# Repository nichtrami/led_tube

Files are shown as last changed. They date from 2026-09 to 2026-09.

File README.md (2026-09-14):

# LED Tube

## Overview
This project controls **2-meter-long LED tubes** built from a **WS2812B LED strip with 120 LEDs**.
The firmware runs on an **ESP32 (Arduino Core)** and supports standalone operation, a custom
**wireless DMX protocol over ESP-NOW**, wired **DMX input**, and an (experimental) **Art-Net** path.

The codebase builds two different devices from the same sources, selected via the `DEVICE_MODE`
build flag in [`platformio.ini`](platformio.ini):

| Device | PlatformIO env | Board | Role |
| --- | --- | ----- | ---- |
| **Tube** | `led_tube` | Seeed XIAO ESP32-S3 | Drives one LED tube and receives commands |
| **Bridge** | `bridge` | ESP32 dev board | Generates/forwards commands to the tubes  |

## Hardware Components
Schematics and PCB designs live in `pcb/`, enclosure models in `body/`.

Datasheets for the components used are not redistributed in this repository. The part numbers are
given in the schematics and can be looked up on the manufacturers' sites.

### User Interface (both devices)
- **Three buttons**: Up, Down, Enter
- **A monochrome 0.91" OLED display** (SSD1306) connected via **I2C**, showing the current menu item

## Operating Modes

### Tube
1. **Standalone** – the tube shows a locally selected color and effect.
2. **Wireless DMX** – the tube listens on a configurable DMX address and renders the data it
   receives from a bridge over ESP-NOW.

### Bridge
1. **Master** – generates beat-synchronized choreography (driven by a configurable BPM) for a
   configurable number of tubes and broadcasts it over ESP-NOW.
2. **DMX** – reads a wired DMX universe (via `esp_dmx`) and forwards the relevant slice to the
   tubes over ESP-NOW.
3. **Art-Net** – receives Art-Net over Ethernet (W5500). *Experimental / partially implemented.*

### Channels
The **Channel** menu item (1–3) maps to distinct Wi-Fi channels for the ESP-NOW link, so multiple
independent light systems can run side by side without interference. The bridge and its tubes must
use the same channel.

## Wireless Protocol
Communication uses **ESP-NOW broadcast** (no pairing). The payload is a lightweight DMX frame:

```
[ size (1 byte) ][ start_address (1 byte) ][ data ... up to 240 bytes ]
```

Each tube occupies `TUBE_DATASET_SIZE` (4) channels: `effect, red, green, blue`.

## Pin Configuration
Pins are defined in [`src/Config.hpp`](src/Config.hpp).

### Tube (Seeed XIAO ESP32-S3)
- **LED data**: GPIO 4
- **OLED (I2C)**: SDA GPIO 3, SCL GPIO 2
- **Buttons**: Up GPIO 9, Down GPIO 7, Enter GPIO 8

### Bridge (ESP32 dev board)
- **LED data**: GPIO 14
- **OLED (I2C)**: SDA GPIO 26, SCL GPIO 25
- **Buttons**: Up GPIO 27, Down GPIO 32, Enter GPIO 33
- **DMX input**: RX GPIO 16, EN/TX GPIO 17
- **Ethernet (W5500, SPI)**: CS GPIO 5, SCK GPIO 18, MISO GPIO 19, MOSI GPIO 23, RST GPIO 4

## Building & Flashing
This is a [PlatformIO](https://platformio.org/) project.

```bash
# Tube firmware
pio run -e led_tube -t upload

# Bridge firmware
pio run -e bridge -t upload
```

Configuration values selected in the on-device menu are persisted to NVS flash and restored on boot.

### Dependencies
Managed automatically by PlatformIO (see [`platformio.ini`](platformio.ini)):
- FastLED
- Adafruit GFX Library
- Adafruit SSD1306
- esp_dmx
- Ethernet
- ArtNet

ESP-NOW / Wi-Fi and `Preferences` (NVS) are provided by the ESP32 Arduino Core.

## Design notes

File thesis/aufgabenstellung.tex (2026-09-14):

% Eigenständig kompilierbare Aufgabenstellung.
% Kompilieren mit XeLaTeX oder LuaLaTeX (wegen fontspec/polyglossia), z. B.:
%   latexmk -xelatex aufgabenstellung_standalone.tex
\documentclass[a4paper,11pt]{article}

\usepackage{polyglossia}
\setdefaultlanguage[spelling=new,babelshorthands=true]{german}
\usepackage{fontspec}
\usepackage{parskip}
\usepackage[left=2.5cm,right=2.5cm,top=2.5cm,bottom=2.5cm]{geometry}

\title{Aufgabenstellung}
\author{}
\date{}

\begin{document}

\begin{center}
  {\Large\bfseries Entwicklung eines funkbasierten Beleuchtungssystems\\
  auf Basis von LED-Röhren für die Veranstaltungstechnik}\\[0.5em]
  {\large Aufgabenstellung}
\end{center}

\bigskip

Der Aufbau professioneller Bühnenbeleuchtung ist durch die kabelgebundene
DMX-Signalverteilung mit einem erheblichen Planungs-, Verkabelungs- und
Zeitaufwand verbunden. Kommerzielle Funklösungen adressieren dieses Problem,
sind jedoch kostenintensiv und primär auf große Produktionen ausgerichtet.
Ziel dieser Arbeit ist die Entwicklung eines kostengünstigen, funkbasierten
Beleuchtungssystems auf Basis von LED-Leuchtröhren, das DMX-Steuersignale
drahtlos an mehrere Beleuchtungseinheiten überträgt und sich ohne Anpassungen
in bestehende DMX-Infrastrukturen integrieren lässt. Das System soll dabei
durchgängig als frei zugängliches Open-Source-Projekt konzipiert und
veröffentlicht werden, um einen niedrigschwelligen Nachbau zu ermöglichen.
Das System besteht aus einer zentralen \emph{Bridge}, welche Steuerdaten
entgegennimmt und verteilt, sowie den empfangenden LED-Leuchtröhren, die die
Daten unmittelbar in Lichtsignale umsetzen.

Im Rahmen der Arbeit sind folgende Teilaufgaben zu bearbeiten:

\begin{itemize}
  \item Analyse des Einsatzszenarios und Ableitung funktionaler sowie
        nicht-funktionaler Anforderungen (u.\,a. Echtzeitverhalten,
        Zuverlässigkeit, Reichweite, Benutzerfreundlichkeit).
  \item Entwurf einer Systemarchitektur aus Bridge und Leuchtröhren auf Basis
        des ESP32 mit Definition eines schlanken, drahtlosen
        Übertragungsprotokolls (ESP-NOW) für die DMX-Datenverteilung.
  \item Implementierung der Firmware für die Betriebsmodi Einzelbetrieb,
        autonomer Master-Modus sowie drahtloser DMX-Modus mit Empfang
        kabelgebundener DMX512-Signale und Weiterleitung an adressierbare Leuchtröhren.
  \item Umsetzung der Ansteuerung der WS2815-LED-Strips, einer menügeführten
        Bedienung über OLED-Display und Taster sowie einer persistenten
        Konfigurationsspeicherung.
  \item Entwurf der Hardware in Form eigener Platinenlayouts (PCB) sowie der
        3D-Gehäuse für Bridge und Leuchtröhren unter Berücksichtigung der
        elektrischen Belastbarkeit und Portabilität.
  \item Experimentelle Evaluierung des Systems in einer realitätsnahen
        Umgebung hinsichtlich Verbindungsstabilität, Übertragungsrate, Latenz
        und Jitter sowie Ableitung verbleibender Optimierungspotenziale.
\end{itemize}

Sämtliche Ergebnisse -- Software, Platinenlayouts und Gehäusemodelle -- werden
als Open-Source-Projekt veröffentlicht, um Nachvollziehbarkeit und
Weiterentwicklung durch Dritte zu ermöglichen.

\end{document}

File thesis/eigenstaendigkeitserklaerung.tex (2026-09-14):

\section*{Eigenständigkeitserklärung}
\label{sec:eigenstaendigkeitserklaerung}

Ich versichere, dass ich diese Bachelorarbeit selbständig angefertigt, alle Hilfen und Hilfsmittel angegeben und alle
wörtlich oder dem Sinne nach aus Veröffentlichungen oder anderen Quellen, insbesondere dem Internet entnommenen
Inhalte, kenntlich gemacht habe. KI-Werkzeuge wurden in dieser Arbeit lediglich zur Korrektur von Rechtschreibung und Grammatik eingesetzt. 
Die Arbeit wurde bisher in gleicher oder ähnlicher Form keiner anderen Prüfungsbehörde vorgelegt und auch nicht veröffentlicht.

\vspace{2cm}

\noindent
\begin{tabular}{@{}p{0.45\textwidth}p{0.45\textwidth}@{}}
\textbf{Ort, Datum:} Leipzig, \today & \textbf{Unterschrift:} \hrulefill \\
\end{tabular}

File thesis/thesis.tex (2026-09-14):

\documentclass[a4paper,10pt]{report}

\usepackage{graphicx}
\usepackage{subcaption}
\usepackage{booktabs}
\usepackage{polyglossia}
\setdefaultlanguage[spelling=new,babelshorthands=true]{german}
\usepackage{fontspec}
\usepackage{parskip}
\usepackage{amsmath}
\usepackage{amsfonts}
\usepackage[backend=biber,style=numeric,babel=other]{biblatex}
\addbibresource{literatur.bib}
\usepackage[hidelinks]{hyperref}
\usepackage[left=2cm,right=2cm,top=3.0cm,bottom=3.0cm]{geometry}
\usepackage[arrow, matrix, curve]{xy}
\usepackage{msc}
\usepackage{float}
\usepackage{xcolor}
\usepackage[edges]{forest}
\usepackage{tikz}
\usetikzlibrary{positioning, arrows.meta, fit, backgrounds, decorations.pathreplacing}
\tikzset{
    archbox/.style   = {draw, rounded corners=2pt, align=center, inner sep=5pt,
                        minimum height=1.05cm, font=\small},
    extern/.style    = {archbox, fill=black!5},
    device/.style    = {archbox, fill=black!12, thick},
    modul/.style     = {archbox, fill=black!3, minimum width=3.3cm},
    huelle/.style    = {draw, dashed, rounded corners=4pt, inner sep=9pt},
    link/.style      = {-{Latex[length=2.2mm]}, thick},
    funk/.style      = {link, dashed},
    beschr/.style    = {font=\footnotesize, align=center, inner sep=2pt}
}
\usepackage{listings}
\lstset{
    language=Python,
    basicstyle=\ttfamily\small,
    keywordstyle=\color{purple}\bfseries,
    commentstyle=\color{gray}\itshape,
    stringstyle=\color{teal},
    numberstyle=\tiny\color{gray!60},
    identifierstyle=\color{black},
    backgroundcolor=\color{gray!5},
    frame=single,
    frameround=tttt,
    framerule=0.5pt,
    framexleftmargin=5pt,
    breaklines=true,
    showstringspaces=false,
    numbers=left,
    numbersep=10pt,
    tabsize=4,
    captionpos=b,
    xleftmargin=10pt,
    xrightmargin=5pt,
    emphstyle=\color{blue!80!black},
    emph={def,class,import,from,as,return,if,elif,else,for,while,try,except,with}
}
%\usepackage{draftwatermark}
%\SetWatermarkText{Entwurf}
%\nofiles

\begin{document}

% Deckblatt
\input{title}

%Abstract
\newpage
\input{abstract}

% Inhaltsverzeichnis
\setcounter{page}{1}
\pagenumbering{arabic}
\tableofcontents

%Leere Seite
\newpage
\null
\newpage

% Kapitel einbinden
\include{chapters/1_einleitung}
\include{chapters/2_grundlagen}
\include{chapters/3_stand_der_technik}
\include{chapters/4_anforderungsanalyse}
\include{chapters/5_systemarchitektur}
\include{chapters/6_implementierung}
\include{chapters/7_evaluierung}
\include{chapters/8_diskussion}

% Anhang
\appendix
\include{chapters/anhang}

% Literaturverzeichnis
\printbibliography

% Eigenständigkeitserklärung
\include{eigenstaendigkeitserklaerung}

\end{document}

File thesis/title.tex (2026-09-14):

\begin{titlepage}
    \vbox{ }
    \vbox{ }
    \begin{center}
% Upper part of the page

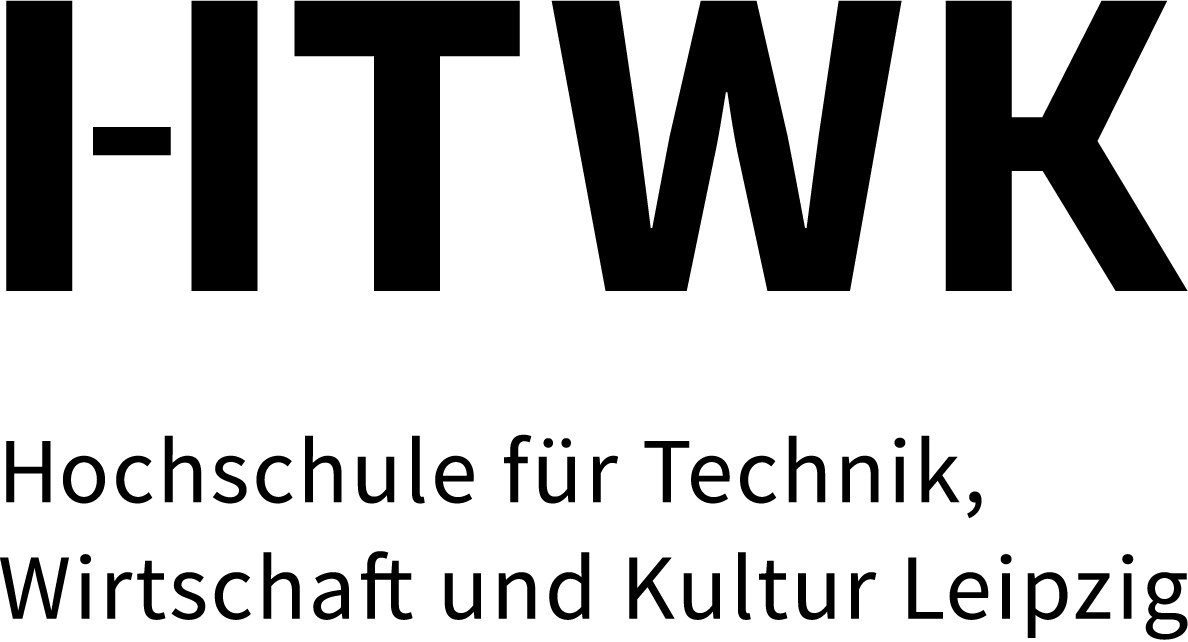
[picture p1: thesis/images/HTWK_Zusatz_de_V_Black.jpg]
        \\[1cm]
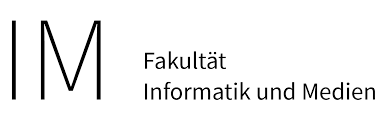
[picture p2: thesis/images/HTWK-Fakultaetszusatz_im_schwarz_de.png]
        \\[1cm]
        
        \vfill
        {\Large Abschlussarbeit zur Erlangung des akademischen Grades}\\[20pt]
        {\Large Bachelor of Science (B.Sc.)}\\[20pt]
        {\Large im Studiengang Bachelor Informatik}\\[10pt]
        {\Large der Fakultät Informatik und Medien}\\[20pt]
        \vbox{}

% Title
        {\LARGE \textbf{Entwicklung eines Beleuchtungssystems}}\\[10pt]
        {\LARGE \textbf{für Veranstaltungen als LED-Leuchtröhren}}\\[10pt]
        {\LARGE \textbf{mit funkgestützter Signalübertragung}}\\[40pt]
        {\Large Rami Hoßbach}\\[10pt]
        {\Large Leipzig, den \today}\\[20pt]
        \vfill

% Bottom of the page
        \begin{tabular}{l l}
            \Large Erstgutachter:  & \Large Prof. Dr.-Ing. Jens Wagner\\[10pt]
            \Large Zweitgutachter: & \Large M.Sc. Marian Ulbricht\\
        \end{tabular}
    \end{center}
\end{titlepage}

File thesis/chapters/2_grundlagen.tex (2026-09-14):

\chapter{Theoretische Grundlagen}
\label{chap:grundlagen}

\section{Eingebettete Systeme}
\label{sec:eingebettete-systeme}

Eingebettete Systeme werden von Marwedel als informationsverarbeitende Systeme 
definiert, die in in ein umgebendes Produkt eingebettet sind und dort dedizierte 
Steuerungs-, Regelungs- oder Überwachungsaufgaben übernehmen \cite{marwedel2021}. 
Im Gegensatz zu universellen Computersystemen sind sie auf einen konkreten 
Anwendungsfall zugeschnitten. Als gemeinsame Merkmale dieser Systemklasse nennt 
Marwedel insbesondere Echtzeitanforderungen sowie Anforderungen an Verlässlichkeit 
und Effizienz \cite{marwedel2021}, letztere äußert sich in ressourcensparender 
Hardware und häufig energiesparenden Betriebsweisen.

Die zunehmende Miniaturisierung und Leistungsfähigkeit moderner Mikrocontroller hat in 
den vergangenen Jahren zu einer breiten Durchdringung eingebetteter Systeme in 
unterschiedlichen Domänen geführt. Insbesondere die 
Integration drahtloser Kommunikationsschnittstellen wie WLAN und Bluetooth in 
kostengünstige Mikrocontroller-Plattformen eröffnet neue Möglichkeiten für verteilte, 
vernetzte Systemarchitekturen.

Im Kontext des entwickelten LED-Tube-Systems bilden eingebettete Systeme die zentrale 
Komponente sowohl der Bridge als auch der einzelnen Tubes. Beide setzen auf den 
ESP32-Mikrocontroller, der im Folgenden näher betrachtet wird.

\subsection{ESP32-Mikrocontroller}
\label{subsec:esp32}

Die Bezeichnung ESP32 steht nicht für einen einzelnen Chip, sondern für eine von 
Espressif Systems entwickelte Familie von System-on-Chips (SoC), deren Mitglieder sich 
in Prozessorarchitektur, Speicherausstattung und Peripherie unterscheiden 
\cite{espressif_esp32}. Kennzeichnend für die gesamte Familie ist die Integration eines 
leistungsfähigen Prozessors und umfangreicher drahtloser Kommunikationsschnittstellen 
(WLAN 802.11 b/g/n sowie Bluetooth beziehungsweise Bluetooth Low Energy) auf einem 
einzigen Baustein. Das namensgebende erste Mitglied der Familie kombiniert dabei einen 
Dual-Core-Prozessor des Typs Xtensa LX6 mit WLAN und Bluetooth 4.2. Seit der Einführung 
im Jahr 2016 hat sich die ESP32-Reihe zu einer der meistverwendeten Plattformen im 
Bereich des Internet of Things (IoT) und eingebetteter Systeme entwickelt. Besonders die 
Kompatibilität mit dem im Hobby- und Maker-Bereich weit verbreiteten Arduino-Ökosystem 
sowie die umfassende Unterstützung durch die Entwicklergemeinschaft haben zur 
Popularität des ESP32 beigetragen.

\subsubsection{Technische Merkmale}
\label{subsubsec:esp32-merkmale}

Es existieren verschiedene Varianten des ESP32, die sich in Bezug auf Speicherkapazität, Anzahl der GPIO-Pins,
integrierte Peripheriefunktionen und unterstützte Kommunikationsschnittstellen unterscheiden.
Die in diesem Projekt verwendeten Varianten verfügen über zwei unabhängige 32-Bit-Prozessorkerne mit einer maximalen 
Taktfrequenz von bis zu 240\,MHz. Diese Dual-Core-Architektur ermöglicht es, 
rechenintensive Aufgaben wie Signalverarbeitung und drahtlose Kommunikation parallel 
auszuführen.

Neben den Kommunikationsschnittstellen bieten die Bausteine der Familie umfangreiche 
Peripheriefunktionen, darunter mehrere UART-, SPI- und I²C-Schnittstellen, 
GPIO-Pins (General Purpose Input/Output), ADCs (Analog-Digital-Wandler), PWM-Kanäle 
(Pulse Width Modulation) sowie kapazitive Berührungssensoren \cite{espressif_esp32}. 

\subsubsection{Software-Entwicklung und Ökosystem}
\label{subsubsec:esp32-software}

Espressif Systems stellt mit dem ESP-IDF (Espressif IoT Development Framework) eine 
umfassende Entwicklungsumgebung bereit, die auf dem FreeRTOS-Echtzeitbetriebssystem 
basiert und native Unterstützung für C/C++-Programmierung bietet. Daneben existiert eine 
breite Community-Unterstützung für alternative Entwicklungsumgebungen wie Arduino IDE, 
PlatformIO sowie MicroPython.

Die Integration des ESP32 in Entwicklungsumgebungen sowie die Verfügbarkeit 
zahlreicher Open-Source-Bibliotheken haben die Einstiegshürde deutlich gesenkt und den 
Einsatz des Mikrocontrollers sowohl im Amateur- als auch im industriellen Kontext 
gefördert.

\subsubsection{Einsatz im entwickelten System}
\label{subsubsec:esp32-system}

Im Rahmen dieser Arbeit bildet der ESP32 die hardwaretechnische Grundlage sowohl für die 
zentrale Bridge als auch für die dezentralen LED-Tubes. Die Dual-Core-Architektur 
ermöglicht die parallele Verarbeitung von Netzwerkkommunikation (ESP-NOW, Art-Net) auf 
einem Kern und die Ansteuerung der LED-Hardware auf dem zweiten Kern.

Die integrierte WLAN-Funktionalität wird für die Implementierung des proprietären 
ESP-NOW-Protokolls genutzt, welches die drahtlose Datenübertragung zwischen Bridge und 
Tubes realisiert. Gleichzeitig erlaubt die Ethernet-Erweiterbarkeit über externe Module 
die Anbindung der Bridge an professionelle Lichtsteuersysteme mittels Art-Net.

Die GPIO-Pins dienen der Ansteuerung der Peripheriekomponenten, etwa der LED-Strips und 
der übrigen in der Schaltung verbauten ICs (Integrated Circuits).
Die Leistungsfähigkeit des ESP32 stellt sicher, dass die zeitkritischen Anforderungen der Lichtsteuerung erfüllt werden können, 
während gleichzeitig die Flexibilität für eventuelle zukünftige Erweiterungen gegeben ist.

\section{Kommunikationsprotokolle}
\label{sec:kommunikationsprotokolle}

\subsection{DMX512}
\label{subsec:dmx512}

DMX512 (Digital Multiplex 512) ist ein weit verbreiteter Industriestandard für die
Steuerung von Bühnen- und Veranstaltungstechnik. Der Standard wurde 1986 vom United 
States Institute for Theatre Technology (USITT) entwickelt und wird heute von der 
Entertainment Services and Technology Association (ESTA) gepflegt. Er wurde seither in 
mehreren Revisionen fortgeschrieben die aktuelle Fassung ist ANSI E1.11-2024 
\cite{ANSI_E1.11_2024}.

\subsubsection{Technische Grundlagen}
\label{subsubsec:dmx512-technik}

DMX512 überträgt Daten seriell und unidirektional über eine differentielle
RS-485-Leitung mit einer Datenrate von 250\,kbit/s \cite{ANSI_E1.11_2024}. Die
Übertragung erfolgt in Form von Paketen, die neben dem einleitenden START-Code bis zu
512 Datenfelder (Slots) umfassen. Jeder Slot wird durch einen 8-Bit-Wert (0--255)
repräsentiert, der beispielsweise die Helligkeit, Farbe oder Position eines Geräts
definiert.

Die physikalische Verbindung erfolgt über eine Daisy-Chain-Topologie, bei der die Geräte
in Reihe geschaltet werden. Der Standard schreibt vor, die Leitung abzuschließen, um
Reflexionen und die daraus folgenden Fehlfunktionen zu vermeiden als Abschluss ist ein
Widerstand von 120\,Ohm vorgesehen. Die Belastung einer DMX512-Linie ist zudem auf 32
Unit Loads begrenzt, wobei jeder Empfängereingang höchstens eine Unit Load darstellen
darf \cite{ANSI_E1.11_2024}. Größere Installationen erfordern daher Verstärker
(DMX-Splitter), die zugleich die nutzbare Leitungslänge erhöhen. Eine maximale
Leitungslänge legt der Standard selbst nicht fest, sie ergibt sich aus den elektrischen
Eigenschaften der RS-485-Strecke und liegt in der Praxis im Bereich einiger hundert
Meter.

\subsubsection{Protokollstruktur}
\label{subsubsec:dmx512-protokoll}

Ein DMX512-Paket beginnt mit einer Reset-Sequenz aus \textit{Break}, einer Unterbrechung
der Datenleitung, dem darauf folgenden \textit{Mark After Break} (MAB) und dem
\textit{START-Code}. Der START-Code kennzeichnet die Art der nachfolgenden Daten für
Beleuchtungsdaten ist der NULL-START-Code mit dem Wert 0x00 vorgesehen. Anschließend
folgen bis zu 512 Datenslots. Für die Zeiten der Reset-Sequenz unterscheidet der
Standard zwischen Sende- und Empfangsseite: Sender müssen einen Break von mindestens
92\,µs und einen MAB von mindestens 12\,µs erzeugen, während Empfänger bereits einen
Break ab 88\,µs und einen MAB ab 8\,µs als Paketbeginn erkennen müssen
\cite{ANSI_E1.11_2024}. Für die Implementierung des Empfängers ist somit die geringere,
für die des Senders die höhere Vorgabe maßgeblich.

Aus Datenrate und Paketaufbau ergibt sich für ein vollständiges Paket mit 513 Slots eine
minimale Aktualisierungszeit von 22,7\,ms und damit eine maximale Wiederholrate von
44\,Hz \cite{ANSI_E1.11_2024} werden weniger Slots übertragen, steigt die erreichbare
Rate entsprechend. Eine bidirektionale Kommunikation ist im regulären Datenpfad nicht
vorgesehen, sodass der Sender keine Rückmeldung über den Status der Empfangsgeräte
erhält.

\subsubsection{Einsatz in der Veranstaltungstechnik}
\label{subsubsec:dmx512-einsatz}

DMX512 hat sich als De-facto-Standard in der professionellen Lichtsteuerung etabliert
und wird von nahezu allen Herstellern unterstützt. Die Einfachheit des Protokolls sowie
die deterministischen Übertragungseigenschaften machen es besonders geeignet für
zeitkritische Anwendungen, bei denen eine zuverlässige Steuerung
erforderlich ist.

Im Kontext des entwickelten LED-Tube-Systems dient der Aufbau des DMX512-Pakets als
Vorbild für das interne Datenformat, in dem die Steuerbefehle repräsentiert werden. Die Bridge kann DMX-Daten sowohl über Art-Net 
(Ethernet) als auch über eine DMX-Schnittstelle (XLR) empfangen und verarbeitet 
diese anschließend zur Übertragung an die LED-Tubes. Dabei bildet die Struktur des 
DMX512-Frames die Grundlage für das entwickelte drahtlose Übertragungsprotokoll, das 
über ESP-NOW an die Tubes übertragen wird. 
Die Orientierung an diesem etablierten Standard ermöglicht eine nahtlose Integration in 
bestehende Lichtsteuersysteme und gewährleistet Kompatibilität mit professioneller 
Steuerungssoftware.

\subsection{Art-Net}
\label{subsec:artnet}

Art-Net ist ein Ethernet-basiertes Kommunikationsprotokoll, das von Artistic Licence
entwickelt wurde und die Übertragung von DMX512-Daten über IP-Netzwerke ermöglicht.
Seit seiner Einführung im Jahr 1998 hat sich Art-Net zu einem weit verbreiteten Standard
in der professionellen Lichtsteuerung entwickelt und wird von zahlreichen
Softwarelösungen und Hardwarekomponenten unterstützt.

Die Etablierung von Art-Net als De-facto-Standard in der professionellen 
Veranstaltungstechnik ist auf die Limitierung klassischer DMX512-Verbindungen 
zurückzuführen. Während eine einzelne DMX-Linie lediglich 512 Kanäle/Byte bereitstellt, 
erfordern moderne Installationen mit einer Vielzahl komplexer Scheinwerfer, 
LED-Pixelmatrizen oder hochauflösenden LED-Wänden häufig mehrere tausend Steuerkanäle. 
Die Art-Net-4-Spezifikation sieht ein theoretisches Maximum von 32.768 DMX-Universen 
vor, wie viele davon tatsächlich übertragen werden können, hängt von der verfügbaren 
Netzwerkbandbreite und der Leistungsfähigkeit der beteiligten Geräte ab 
\cite{artnet4}. Art-Net adressiert damit die gestiegenen Bandbreitenanforderungen 
professioneller Lichtinstallationen. Insbesondere bei der Ansteuerung von LED-Pixelmonitoren, 
bei denen jeder einzelne Pixel mehrere DMX-Kanäle (typischerweise RGB oder RGBW) 
beansprucht, stößt klassisches DMX512 schnell an seine Grenzen, während Art-Net eine 
skalierbare Lösung bietet.

\subsubsection{Funktionsweise und Architektur}
\label{subsubsec:artnet-funktion}

Art-Net kapselt DMX512-Daten in UDP-Pakete (User Datagram Protocol) und überträgt diese
über ein Standard-Ethernet-Netzwerk. Während eine DMX512-Linie auf ein einzelnes
RS-485-Segment mit einem Universum von 512 Kanälen beschränkt ist, ermöglicht Art-Net die
gleichzeitige Übertragung mehrerer Universen über eine einzige Netzwerkverbindung.

Ein Art-Net-Netzwerk besteht typischerweise aus einem oder mehreren \textit{Controllern}
(z.\,B. Lichtsteuerungssoftware), die Art-Net-Pakete senden, sowie \textit{Nodes}, die
diese Pakete empfangen und in DMX512-Signale umwandeln. Die Nodes können dabei sowohl
als Sender als auch als Empfänger fungieren, wodurch bidirektionale Kommunikation
möglich ist.

\subsubsection{Protokollstruktur}
\label{subsubsec:artnet-protokoll}

Jedes Art-Net-Paket beginnt mit einer acht Byte langen, nullterminierten Kennung, 
gefolgt von einem OpCode, der den Pakettyp bestimmt, der
Protokollversion sowie weiteren Verwaltungsinformationen \cite{artnet4}. Das Ziel wird
über die Port-Address adressiert, eine 15\,Bit breite Zahl, die sich aus den
Feldern Net, Sub-Net und Universe34 zusammensetzt und die 32.768 möglichen Universen
abbildet \cite{artnet4}. Der Nutzdatenbereich umfasst bis zu 512 Byte, entsprechend
einem DMX512-Universum.

\subsubsection{Vorteile gegenüber klassischem DMX512}
\label{subsubsec:artnet-vorteile}

Durch die Nutzung von Ethernet-Infrastruktur bietet Art-Net mehrere Vorteile gegenüber
klassischem DMX512:
\begin{itemize}
    \item \textbf{Skalierbarkeit:} Mehrere DMX-Universen können parallel über eine
          einzige Netzwerkverbindung übertragen werden.
    \item \textbf{Reichweite:} Die Ausdehnung ist nicht mehr durch die Grenzen eines
          einzelnen RS-485-Segments bestimmt, sondern kann mit
          Standard-Netzwerkkomponenten nahezu beliebig erweitert werden.
    \item \textbf{Bidirektionalität:} Rückmeldungen über Gerätestatus und Fehlerzustände sind möglich.
    \item \textbf{Flexibilität:} Bestehende IT-Infrastrukturen können genutzt werden,
          wodurch separate DMX-Verkabelung entfällt.
\end{itemize}

\subsubsection{Einsatz im entwickelten System}
\label{subsubsec:artnet-system}

Im entwickelten LED-Tube-System dient Art-Net als Schnittstelle zur Anbindung an
professionelle Lichtsteuerungssoftware. Die Bridge empfängt Art-Net-Pakete über ihre
Ethernet-Schnittstelle und extrahiert daraus die DMX512-Daten, die anschließend wie im
kabelgebundenen DMX-Betrieb weiterverarbeitet werden.

Darüber hinaus ist ein kabelgebundener Pixelsteuerungsmodus vorgesehen, in dem die
einzelnen Pixel der LED-Strips über eine Datenleitung angesprochen werden. Die Hardware
der Bridge ist dafür bereits vorbereitet
(Abschnitt~\ref{subsec:bridge-pcb}), die Umsetzung dieses Modus ist jedoch nicht
Gegenstand der vorliegenden Arbeit. Durch die Unterstützung von Art-Net bleibt das System
mit einer Vielzahl bestehender Steuerungslösungen kompatibel.

\section{Drahtlose Kommunikation}
\label{sec:drahtlose-kommunikation}

Drahtlose Kommunikation stellt einen zentralen Bestandteil moderner eingebetteter
Systeme dar, insbesondere im Kontext verteilter Architekturen und modularer
Installationen. Im Vergleich zu kabelgebundenen Kommunikationsformen bietet sie eine
höhere Flexibilität und vereinfacht die physische Integration einzelner Komponenten.
Gleichzeitig ergeben sich jedoch neue Herausforderungen hinsichtlich Latenz,
Zuverlässigkeit, Störanfälligkeit und Energieeffizienz.

Im vorliegenden System wird drahtlose Kommunikation eingesetzt, um Steuerdaten von einer
zentralen Bridge an mehrere räumlich verteilte LED-Tubes zu übertragen. Zunächst werden
das genutzte Frequenzband und der Zugriff auf das Übertragungsmedium betrachtet, da
beide das Verhalten der Funkstrecke unter Last bestimmen. anschließend wird das
eingesetzte Protokoll ESP-NOW vorgestellt.

\subsection{Das 2,4-GHz-Band und der Zugriff auf das Übertragungsmedium}
\label{subsec:24ghz-medienzugriff}

Die Übertragung erfolgt im Frequenzbereich von 2400 bis 2483,5\,MHz. Dieses Band steht
weltweit anmeldefrei zur Verfügung. in Europa regelt die harmonisierte Norm
ETSI EN 300 328 die Nutzung durch Breitband-Datenübertragungssysteme
\cite{etsi_en300328}. Genutzt wird es nicht exklusiv, sondern gemeinsam von WLAN,
Bluetooth, Zigbee und weiteren Funkanwendungen, die die genannte Norm ausdrücklich
gemeinsam erfasst. Für ein Steuerungssystem
folgt daraus, dass die verfügbare Übertragungskapazität nicht allein von der eigenen
Hardware abhängt, sondern von der Belegung des Kanals durch fremde Sender.

Innerhalb des Bands definiert IEEE 802.11 in Europa dreizehn Kanäle im Abstand von je
5\,MHz, während ein Kanal eine Bandbreite von etwa 20\,MHz belegt. 

Der Zugriff auf das gemeinsam genutzte Medium erfolgt nach dem in IEEE 802.11
festgelegten Verfahren CSMA/CA (Carrier Sense Multiple Access with Collision
Avoidance) \cite{ieee80211_2024}. Eine Station prüft vor dem Senden, ob der Kanal frei
ist, wartet bei belegtem Kanal ab und beginnt die Übertragung erst nach einer zusätzlich
zufällig gewählten Wartezeit (Backoff). Kollisionen werden dadurch vermieden, gleichzeitig verzögern sich
Sendevorgänge bei hoher Fremdlast oder unterbleiben ganz. Für die Bewertung der
Zuverlässigkeit ist diese Unterscheidung wesentlich: Eine ausgelastete Umgebung führt
nicht zu verfälschten, sondern zu verspäteten oder ausbleibenden Paketen. Die
messtechnische Untersuchung dieses Effekts erfolgt in
Abschnitt~\ref{sec:stoerfestigkeit}.

\subsection{ESP-NOW}
\label{subsec:espnow-protokoll}
Das von Espressif Systems entwickelte ESP-NOW-Protokoll stellt eine proprietäre, verbindungslose 
Kommunikationstechnologie dar, die primär für Low-Power-Anwendungen im Bereich des Internet of Things (IoT) konzipiert wurde. 
Im Gegensatz zu herkömmlichen WLAN-Verbindungen nach dem IEEE 802.11-Standard, welche eine zeit- und 
energieintensive Assoziierung mit einem Access Point sowie den vollständigen Durchlauf des TCP/IP-Stacks erfordern, 
operiert ESP-NOW unmittelbar auf der Sicherungsschicht (Data Link Layer) des ISO-OSI-Modells.

Technisch basiert die Übertragung auf sogenannten \textit{IEEE 802.11 Vendor Specific Action Frames} \cite{espressif_espnow}. 
Diese ermöglichen es den Knotenpunkten, Datenpakete direkt über die MAC-Adresse zu adressieren, ohne dass ein 
vorheriger Handshake oder eine IP-Zuweisung notwendig ist. Daraus resultiert eine signifikante Reduktion 
der Latenzzeit sowie des energetischen Overheads, da die Funkmodule lediglich für die Dauer der Übertragung aktiviert werden müssen.

Trotz der verbindungslosen Natur unterstützt das Protokoll eine optionale bidirektionale 
Kommunikation durch Bestätigungs-Frames (Acknowledgements) sowie eine Verschlüsselung der 
Action Frames \cite{espressif_espnow}. Die maximale Nutzlast 
je Datenpaket beträgt in der ersten Version 250 Byte und wurde in der zweiten 
Version auf 1470 Byte erhöht \cite{espressif_espnow}. Mit Version 1.0 lässt sich somit nur 
etwa ein halber DMX512-Frame übertragen, während Version 2.0 ein vollständiges 
DMX-Universum in einem einzigen Paket aufnehmen kann.

Version 2 ist abwärtskompatibel zu Version 1, sodass ältere Geräte weiterhin mit der neuen Version kommunizieren können, 
jedoch nur die geringere Payload-Größe von 250 Byte nutzen können.
Die Standard-Übertragungsrate gibt Espressif mit 1\,Mbit/s an \cite{espressif_espnow}.

ESP-NOW verwendet ein Peer-to-Peer- beziehungsweise Broadcast-Kommunikationsmodell, bei
dem Datenpakete direkt zwischen den beteiligten Knoten ausgetauscht werden. Für die
gerichtete Übertragung muss jeder Empfänger zuvor als Peer registriert werden, wobei die
Zahl gleichzeitig registrierter Peers auf 20 begrenzt ist \cite{espressif_espnow}. Diese
Begrenzung entfällt im Broadcast-Betrieb, da dort sämtliche Empfänger über eine einzige
Broadcast-Adresse erreicht werden.

\subsubsection{Latenz, Zuverlässigkeit und Einschränkungen}
\label{subsubsec:espnow-eigenschaften}

Durch den Verzicht auf den vollständigen WLAN-Stack weist ESP-NOW in der Regel eine
geringere Latenz als klassische WLAN-Kommunikation auf. Gleichzeitig existieren jedoch
keine integrierten Mechanismen zur garantierten Zustellung oder zur Reihenfolgekontrolle
von Paketen. Der Sendestatus, den die Anwendung nach einem Sendevorgang erhält, bezieht
sich ausschließlich auf die MAC-Schicht, ob die Daten die Anwendungsschicht des
Empfängers erreichen, ist damit ausdrücklich nicht sichergestellt
\cite{espressif_espnow}.

Die Zuverlässigkeit der Übertragung hängt daher stark von den Umgebungsbedingungen, der
Anzahl der beteiligten Knoten sowie der Paketfrequenz ab. Da ESP-NOW auf 802.11-Frames
aufsetzt, unterliegt es zudem dem in
Abschnitt~\ref{subsec:24ghz-medienzugriff} beschriebenen Medienzugriff: Bei hoher
Kanalauslastung verzögern sich Sendevorgänge oder unterbleiben ganz. Paketverluste sind
somit prinzipiell möglich und müssen auf Anwendungsebene berücksichtigt werden.

\subsubsection{Bedeutung für das entwickelte System}
\label{subsubsec:espnow-system}

ESP-NOW bildet die Grundlage für die drahtlose Übertragung von DMX-Steuerdaten von der
Bridge zu den LED-Tubes. Die geringe Latenz und der geringe Overhead machen das
Protokoll besonders geeignet für zeitkritische Steuerinformationen, wie sie in der
Lichtsteuerung erforderlich sind.

Gleichzeitig stellt die fehlende Zustellgarantie eine zentrale Herausforderung dar, die
im Rahmen dieser Arbeit durch experimentelle Untersuchungen der Verbindungsstabilität
analysiert wird. Die Ergebnisse dieser Untersuchungen bilden die Basis für die Bewertung
der Eignung von ESP-NOW als drahtlose Alternative zu kabelgebundenen DMX-Verbindungen.

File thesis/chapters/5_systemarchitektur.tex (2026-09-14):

\chapter{Systemarchitektur}
\label{chap:systemarchitektur}

Basierend auf den im vorherigen Kapitel ermittelten Anforderungen wird im Folgenden die 
Systemarchitektur des drahtlosen Beleuchtungssystems vorgestellt. 
Die Architektur beschreibt die grundlegende Struktur des Systems, die ausgewählten 
Hardwarekomponenten sowie deren Zusammenwirken zur Realisierung der angestrebten Funktionalität. 
Während dieses Kapitel die konzeptionellen und strukturellen Entscheidungen – insbesondere 
hinsichtlich der Hardware – aufzeigt, wird die konkrete technische Umsetzung 
in Kapitel~\ref{chap:implementierung} (Implementierung) behandelt.

\section{Systemüberblick}
\label{sec:systemueberblick}

Das entworfene System setzt sich aus zwei Hauptkomponenten zusammen: einer zentralen Sendeeinheit (Bridge) und 
mehreren dezentralen Empfangseinheiten (LED-Leuchtröhren). 
Die Bridge fungiert als zentraler Kommunikationsknotenpunkt, welcher externe Steuersignale 
aus der Veranstaltungstechnik – wahlweise über DMX oder Art-Net – entgegennimmt, verarbeitet und in 
ein systeminternes Protokoll übersetzt. 
Anschließend verteilt sie die Daten drahtlos an die angeschlossenen Leuchtröhren.

Die LED-Leuchtröhren agieren als verteilte Aktoren. 
Sie empfangen die von der Bridge ausgesendeten Steuerdaten und setzen diese unmittelbar in Lichtsignale um. 
Darüber hinaus verfügen sie über einen autarken Standalone-Modus, bei dem keine Verbindung zur Bridge notwendig ist. 

Aus dieser Aufteilung ergeben sich die im Folgenden beschriebenen Strukturen: der
Signalfluss je Betriebsmodus, die Auswahl der Hardwarekomponenten, die Gliederung der
Software sowie die Verfahren, mit denen die Daten zwischen den Komponenten übertragen
und verarbeitet werden.

Abbildung~\ref{fig:systemueberblick} zeigt die Komponenten des Systems und die
Verbindungen zwischen ihnen.

\begin{figure}[H]
    \centering
    \begin{tikzpicture}[node distance=1.1cm and 2.3cm]
        \node[extern] (pult) {Lichtsteuerung\\(Pult oder Software)};
        \node[device, right=of pult] (bridge) {\textbf{Bridge}\\ESP32};
        \node[archbox, right=of bridge, yshift=1.7cm] (t1)
            {Leuchtröhre 1\\\footnotesize XIAO ESP32-S3 + WS2815};
        \node[archbox, right=of bridge] (t2)
            {Leuchtröhre 2\\\footnotesize XIAO ESP32-S3 + WS2815};
        \node[archbox, right=of bridge, yshift=-1.7cm] (tn)
            {Leuchtröhre $n$\\\footnotesize XIAO ESP32-S3 + WS2815};

        \draw[link] (pult) -- node[beschr, above] {DMX512\\Art-Net} (bridge);
        \draw[funk] (bridge) -- (t1);
        \draw[funk] (bridge) -- node[beschr, above] {ESP-NOW} (t2);
        \draw[funk] (bridge) -- (tn);

        \node[beschr, below=0.15cm of bridge] {lokales Bedienmenü};
        \node[beschr, below=0.15cm of tn] {lokales Bedienmenü};
    \end{tikzpicture}
    \caption{Systemüberblick: Die Bridge verteilt das kabelgebunden empfangene Steuersignal per Broadcast an alle Leuchtröhren.}
    \label{fig:systemueberblick}
\end{figure}

\section{Betriebsmodi und Signalfluss}
\label{sec:betriebsmodi-signalfluss}

Der Signalfluss im System variiert je nach Betriebsmodus, wobei die grundlegenden Datenpfade und 
Interaktionen zwischen den Komponenten im Folgenden erläutert werden.

 \subsection{Standalone-Modus (Leuchtröhre)}
\label{subsec:signalfluss-einzelbetrieb}

Im Standalone-Modus agieren die LED-Leuchtröhren autark, ohne eine Verbindung zur Bridge.
Die Steuerung erfolgt über die integrierte Benutzeroberfläche der Röhren, bestehend aus 
einem OLED-Display und Navigationsschaltern.
Der interne Controller der Röhre generiert die Lichtsignale basierend auf den Benutzereingaben 
und schickt diese direkt an die LEDs weiter.
In diesem Modus findet keine Kommunikation mit der Bridge statt, und die Röhren arbeiten unabhängig voneinander.

\subsection{DMX-Modus}
\label{subsec:signalfluss-dmx-betrieb}

Im DMX-Modus empfängt die Bridge die Steuerdaten über die DMX- oder die Art-Net-Schnittstelle, verarbeitet diese und leitet 
sie drahtlos an die Leuchtröhren weiter.
Die Bridge fungiert als DMX-zu-ESP-NOW-Gateway: Die DMX-Daten werden in ein internes, an
DMX angelehntes Protokoll übersetzt und über das integrierte Wi-Fi-Modul an die Röhren
gesendet.
Der Controller der Röhre empfängt die Daten über das integrierte Wi-Fi-Modul, validiert diese und setzt sie 
in die entsprechenden LED-Signale um.
Die Steuerbefehle pro Röhre enthalten 4 Bytes. 1 Byte für die Wahl eines vordefinierten Effekts und 3 Bytes für die RGB-Farbwerte.

Welche der beiden Eingangsschnittstellen die Bridge auswertet, wird an ihrem Bedienmenü als
eigener Eintrag der Moduswahl festgelegt: Der DMX-Modus liest das Universum über die
RS-485-Schnittstelle ein, der Art-Net-Modus über die Ethernet-Schnittstelle. Diese
Unterscheidung betrifft ausschließlich die Empfangsstufe der Bridge. Ab der Überführung in
das interne Transportformat sind beide Pfade identisch. Für die Leuchtröhren ist die
Herkunft des Universums nicht erkennbar, sie verbleiben in beiden Fällen im DMX-Modus.
\begin{figure}[H]
	\centering
	
	\caption{Signalfluss im DMX-Modus}
	\label{fig:signalfluss-dmx-betrieb}
\end{figure}

\section{Hardware-Architektur}
\label{sec:hardware-architektur}

Die Auswahl der Hardwarekomponenten erfolgte primär unter den Gesichtspunkten der Rechenleistung für 
Echtzeitverarbeitung, der Verfügbarkeit notwendiger Kommunikationsschnittstellen sowie der räumlichen und 
energetischen Restriktionen. Als Basis für beide Systemkomponenten wurden Mikrocontroller der ESP32-Familie gewählt. 
Diese bieten neben einer hohen Taktrate und ausreichend GPIO-Pins vor allem eine integrierte Wi-Fi-Schnittstelle, welche 
die geforderte drahtlose Vernetzung ohne zusätzliche externe Funkmodule ermöglichen und somit das Systemdesign verschlanken.
Abbildung~\ref{fig:hardware-architektur} stellt den Aufbau beider Geräte gegenüber.

\begin{figure}[H]
    \centering
    \begin{tikzpicture}[x=1cm, y=1cm]
        % --- Bridge ---
        \node[archbox, minimum width=3.2cm] (in)   at (0,0)      {DMX512 (RS-485)\\Art-Net (Ethernet)};
        \node[device,  minimum width=2.8cm] (esp)  at (4.9,0)    {ESP32-32U};
        \node[archbox, minimum width=2.4cm] (ant1) at (9.2,0)    {externe Antenne};
        \node[archbox, minimum width=2.8cm] (ui1)  at (4.9,-1.9) {OLED-Display\\+ 3 Taster};

        \draw[link] (in)  -- (esp);
        \draw[link] (esp) -- (ant1);
        \draw[link, {Latex[length=2mm]}-{Latex[length=2mm]}] (esp) -- (ui1);
        \node[beschr, right=0.25cm of ui1] {Versorgung: 5\,V über USB-C};

        \begin{scope}[on background layer]
            \node[huelle, fit=(in)(esp)(ant1)(ui1),
                  label={[font=\small\bfseries]above:Bridge}] {};
        \end{scope}

        % --- Leuchtröhre ---
        \node[archbox, minimum width=3.2cm] (strip) at (0,-5.2)   {WS2815-Strip\\\footnotesize 120 Pixel};
        \node[device,  minimum width=2.8cm] (xiao)  at (4.9,-5.2) {XIAO ESP32-S3};
        \node[archbox, minimum width=2.4cm] (ant2)  at (9.2,-5.2) {externe Antenne};
        \node[extern,  minimum width=3.2cm] (pwr2)  at (0,-7.3)   {12\,V-Netzteil};
        \node[archbox, minimum width=2.8cm] (buck)  at (4.9,-7.3) {Step-Down\\\footnotesize 12\,V $\rightarrow$ 5\,V};
        \node[archbox, minimum width=2.4cm] (ui2)   at (9.2,-7.3) {OLED-Display\\+ 3 Taster};

        \draw[link] (xiao) -- (strip);
        \draw[link] (ant2) -- (xiao);
        \draw[link] (pwr2) -- (strip);
        \draw[link] (pwr2) -- (buck);
        \draw[link] (buck) -- (xiao);
        \draw[link, {Latex[length=2mm]}-{Latex[length=2mm]}] (ui2) -- (xiao);

        \begin{scope}[on background layer]
            \node[huelle, fit=(strip)(xiao)(ant2)(pwr2)(buck)(ui2),
                  label={[font=\small\bfseries]above:Leuchtröhre}] {};
        \end{scope}

        \draw[funk] (ant1) -- node[beschr, right=1mm, pos=0.62] {ESP-NOW} (ant2);
    \end{tikzpicture}
    \caption{Hardware-Architektur beider Gerätetypen: gemeinsame Bedienhardware und gemeinsamer Funkweg, unterschiedliche Schnittstellen.}
    \label{fig:hardware-architektur}
\end{figure}

\subsection{Bridge}
\label{subsec:bridge-hardware}

Die Bridge übernimmt die Aufgabe der Protokollkonvertierung und Datenverteilung. 
Als zentrale Steuereinheit kommt ein ESP32-32U Entwicklungsboard zum Einsatz. Dieser Mikrocontroller bietet 
die entsprechende Rechenleistung um die Echtzeitverarbeitung der eingehenden DMX- und Art-Net-Datenströme zu gewährleisten, 
und verfügt über ausreichend GPIOs für die Anbindung der notwendigen Peripherie.

Zur physikalischen Integration in die bestehende Infrastruktur ist die Bridge mit dedizierten Schnittstellen ausgestattet. 
Für den DMX-Empfang wird ein RS-485-Transceiver (SN75176) verwendet, der als Pegelwandler zwischen den 
differenziellen DMX-Signalen nach RS-485-Standard und den TTL-Signalen des ESP32 agiert. 
Für den Art-Net-Betriebsmodus ist ein Ethernet-Modul vom Typ USR-ES1 integriert, welches den physikalischen 
Netzwerkzugriff für den Art-Net-Empfang gewährleistet.

Die Weiterleitung der verarbeiteten Steuerdaten an die Leuchtröhren erfolgt über das integrierte 
Wi-Fi-Modul des ESP32. Zur Erhöhung der Reichweite und Kommunikationsstabilität im störanfälligen Bühnenumfeld ist 
eine externe Antenne vorgesehen.

Die primäre Spannungsversorgung der Bridge-Komponenten erfolgt per 5V-USB-C-Anschluss direkt über das ESP32-Development-Board. 
Zur Erfüllung der Anforderungen bezüglich Systemkonfiguration und Benutzerfreundlichkeit verfügt das Bedienpanel über 
ein monochromes OLED-Display sowie drei Taster für die Menüführung. 
Es wurde exakt dieselbe Hardwarekombination wie bei der Röhre gewählt, um die Handhabung 
intuitiv und komponentenübergreifend einheitlich zu gestalten.

\subsection{LED-Leuchtröhren}
\label{subsec:led-leuchtroehren-hardware}

Die LED-Leuchtröhren unterliegen baulichen Beschränkungen aufgrund des schlanken Formfaktors bei einem Außendurchmesser von 40\,mm. 
Aus diesem Grund wurde für die Steuerung der \textit{XIAO ESP32-S3} Mikrocontroller ausgewählt. 
Dieser zeichnet sich durch einen besonders kleinen Formfaktor bei ausreichend verfügbaren GPIO-Pins 
und einem dedizierten Anschluss für eine externe WLAN-Antenne aus.

Als Leuchtmittel werden LED-Streifen des Typs WS2815 mit einer Dichte von 60 LEDs pro Meter verwendet. 
Der WS2815 teilt dasselbe Kommunikationsprotokoll wie der weitverbreitete WS2812B (5V-TTL-Logikpegel), 
verfügt jedoch über einen integrierten Spannungsregler und wird mit einer Arbeitsspannung von 12V betrieben. 
Die Anhebung der Betriebsspannung verringert den Spannungsabfall bei längeren Kabel- und
Streckenführungen. Zudem müssen die verwendeten Komponenten nur auf geringere
Stromstärken ausgelegt werden.

Der zusätzliche schaltungstechnische Aufwand zur Erzeugung der Betriebsspannung von 5V (für die restliche Elektronik) wird 
durch die Vorteile der 12V-LED-Architektur kompensiert. 
Zur Realisierung kommt ein kompakter DC-DC-Step-Down-Wandler zum Einsatz, der die von einem externen 12V-Netzteil 
bezogene Eingangsspannung auf 5V reduziert. 
Da der XIAO ESP32-S3 über einen eigenen On-Board-Spannungsregler verfügt, kann das 5V-Niveau direkt 
an dessen VCC-Eingangspin anliegen. 
Dieser transformiert die anliegende Spannung weiter auf die nominelle Chipspannung von 3,3V.

Für die Kommunikation kommen bei den Röhren die reziproken Gegenstücke der Bridge-Sender zum Einsatz: 
Das drahtlose Signal wird über die Wi-Fi-Schnittstelle des ESP32-S3 (mit externer Antenne) demoduliert.

Wie beim Steuergerät umfasst das Human-Machine-Interface auch hier ein monochromes OLED-Display 
sowie drei Navigationsschalter. 
Die konkreten Pinzuteilungen, Schaltungsdetails und Platinenentwürfe der Baugruppen
werden in Kapitel~\ref{chap:implementierung} erläutert.

\section{Software-Architektur}
\label{sec:software-architektur}

Das Software-Design des Systems folgt einem modularen und objektorientierten Ansatz. 
Ein zentraler Aspekt der Architektur ist die Verwendung derselben Codebasis für beide 
Geräteklassen (Bridge und Leuchtröhre). Durch bedingte Kompilierung wird mittels Umgebungsvariablen je nach 
Zielsystem entschieden, welche Logikblöcke eingebunden werden, was Redundanzen vermeidet und 
die Wartbarkeit erhöht.
Abbildung~\ref{fig:software-architektur} zeigt die resultierende Gliederung.

\begin{figure}[H]
    \centering
    \begin{tikzpicture}[x=1cm, y=1cm]
        \node[device, text width=4.7cm, align=center] (bfw) at (0,0)
            {\textbf{Bridge-Firmware}\\[2pt]\footnotesize DMX- und Art-Net-Eingang,
             Effektgenerierung im Master-Modus, Adressvergabe};
        \node[device, text width=4.7cm, align=center] (tfw) at (6.4,0)
            {\textbf{Leuchtröhren-Firmware}\\[2pt]\footnotesize Funkempfang, Auswertung
             der eigenen Adresse, Rendering};

        \node[modul] (m1) at (-1.3,-2.9) {Menü und Display};
        \node[modul] (m2) at (3.2,-2.9)  {Drahtlose Kommunikation};
        \node[modul] (m3) at (7.7,-2.9)  {LED-Steuerung};

        \begin{scope}[on background layer]
            \node[huelle, fit=(m1)(m2)(m3),
                  label={[font=\small\bfseries]below:Gemeinsame Module}] (hull) {};
        \end{scope}

        \draw[link] (bfw.south) -- (hull.north -| bfw.south);
        \draw[link] (tfw.south) -- (hull.north -| tfw.south);
    \end{tikzpicture}
    \caption{Gliederung der Software: gemeinsame Hardwareabstraktion, zur Übersetzungszeit ausgewählte gerätespezifische Firmware.}
    \label{fig:software-architektur}
\end{figure}

\subsection{Modulare Struktur und geteilte Komponenten}
\label{subsec:gemeinsame-softwarekomponenten}

Um die Kernfunktionen abzubilden, ist die Software in funktional getrennte Module unterteilt, 
die geräteübergreifend grundlegende Aufgaben zur Hardwareabstraktion übernehmen:

\begin{itemize}
    \item \textbf{Benutzerinteraktion (Menü und Display):} Kapselt die Verwaltung lokaler 
    Einstellungen, sichert Konfigurationen persistent und visualisiert Systemparameter für den Nutzer.
    \item \textbf{Drahtlose Kommunikation:} Stellt eine generische Abstraktionsschicht 
    für das Senden und Empfangen der systeminternen Datenpakete über das Funknetzwerk bereit.
    \item \textbf{Lichterzeugung (LED-Controller):} Übernimmt die logische Übersetzung von 
    rohen Datenwerten (Farben, Parameter oder Pixelarrays) in dynamische Lichtsignale
\end{itemize}

Ein übergeordneter Steuerungsprozess orchestriert diese Module, aktualisiert das System und 
etabliert – abhängig vom aktuellen Betriebsmodus – den direkten Datenfluss zwischen Peripherie 
und Aktoren.

\subsection{Gerätespezifische Firmware-Profile}
\label{subsec:geraetespezifische-firmware}

Aufbauend auf den gemeinsamen Modulen fokussieren sich Bridge und Leuchtröhre jeweils auf 
ihre dedizierten Aufgaben innerhalb der Systemtopologie:

\textbf{Bridge-Firmware:} \\
Die Software der Bridge agiert primär als Gateway. Sie initiiert 
zusätzliche spezialisierte Komponenten zum Einlesen und Verarbeiten externer Protokolle 
(DMX und Art-Net). Um Latenzen im Netzwerkverkehr zu minimieren, trennt das Architekturdesign 
Protokoll-Parsing vom regulären Ausgabezyklus. 
Dies ermöglicht das parallele Verarbeiten von eingehenden Datenströmen, während die Ausgabe 
an die Röhren kontinuierlich und ohne Unterbrechungen erfolgt.
Anschließend werden die aufbereiteten Datenpakete für die drahtlose Verteilung
bereitgestellt.

\textbf{Leuchtröhren-Firmware:} \\
Das Profil der Leuchtröhren zeichnet sich durch einen reaktiven, schlanken Ausführungszyklus 
aus, um Framedrops zu vermeiden und Latenzen zu minimieren:

\begin{itemize}
    \item \textbf{Autarker Betrieb:} Die Lichtsignalerzeugung agiert komplett losgelöst und speist 
    aktuelle User-Inputs in die eigene Lichtdarstellung ein.
    \item \textbf{Drahtloser Empfang:} Das System fragt fortlaufend den aktuellen Daten-Payload 
    für die eigene Geräteadresse aus der Funkschnittstelle ab und projiziert identifizierte Werte 
    umgehend auf die Pixel.
\end{itemize}

\section{Übertragungstechnologien und Protokolle}
\label{sec:uebertragungstechnologien}

Während Abschnitt~\ref{sec:datenfluss-und-signalverarbeitung} den inneren Signalablauf 
der Softwaremodule beschreibt, definiert dieser Abschnitt die netzwerktechnischen Konzepte und 
verwendeten Protokolle, um die Brücke zwischen den physikalischen Schnittstellen und 
den Software-Logikblöcken zu schließen.

\subsection{Drahtlose Übertragung über ESP-NOW}
\label{subsec:drahtlose-uebertragung}

Für die drahtlose Kommunikation wurde das herstellerspezifische
\textit{ESP-NOW}-Protokoll von Espressif gewählt. Seine technischen Eigenschaften sind in
Abschnitt~\ref{subsec:espnow-protokoll} beschrieben. Ausschlaggebend waren zwei
Eigenschaften, die unmittelbar auf die Anforderungen an Latenz und Stabilität einzahlen.

Erstens arbeitet das Protokoll verbindungslos. Damit entfallen nicht nur die
zeitaufwändigen Assoziierungsvorgänge eines Access-Point-Client-Modells, sondern auch die
Verbindungszustände, die im laufenden Betrieb verloren gehen und wiederhergestellt werden
müssten. Das System benötigt keine Netzwerkinfrastruktur und kann folglich auch nicht
durch deren Ausfall beeinträchtigt werden.

Zweitens adressiert die Bridge sämtliche Röhren über eine gemeinsame Broadcast-Adresse.
Der Sendeaufwand ist dadurch unabhängig von der Anzahl der Empfänger, und alle Röhren
erhalten denselben Datenstand innerhalb desselben Übertragungsfensters, was die
Voraussetzung für die in Abschnitt~\ref{subsec:synchronisation-roehem} beschriebene
Synchronisation ohne eigenes Zeitprotokoll. Der Broadcast-Betrieb kennt allerdings keine
Empfangsbestätigung. Die fehlende Zustellgarantie wird deshalb dadurch ausgeglichen, dass
die Bridge denselben Lichtzustand fortlaufend erneut aussendet: Geht eine Aussendung
verloren, trägt die nächste denselben Wert. Wie wirksam dieses Verfahren ist, untersucht
Kapitel~\ref{chap:evaluierung}.

\subsection{Kabelgebundene Schnittstellen}
\label{subsec:kabelgebundene-uebertragung}

Die Anbindung an die vorhandene Infrastruktur, Lichtpulte und Steuerungssoftware
erfolgt über DMX512 als primäres Eingangsprotokoll
(Abschnitt~\ref{subsec:dmx512}). Die Architektur nutzt dabei die Robustheit der
differentiellen RS-485-Übertragung, um die Signale störungssicher einzulesen, bevor sie
in das interne Format überführt werden. Damit fügt sich die Bridge ohne Anpassungen in
bestehende DMX-Strecken ein und erscheint dem Lichtpult als gewöhnliches Endgerät.

Alternativ nimmt die Bridge dieselben Steuerdaten über Art-Net entgegen
(Abschnitt~\ref{subsec:artnet}). Art-Net dient dabei ausschließlich als
Transportweg für ein DMX-Universum über eine Ethernet-Verbindung. Die Daten sind
inhaltlich identisch zu den über RS-485 empfangenen und durchlaufen ab der
Normalisierung denselben Verarbeitungspfad. Da die Bridge jedoch stets nur eine der beiden
Schnittstellen auswertet, ist die Wahl der Quelle als eigener Eintrag der Moduswahl
ausgeführt. Am Verhalten der Leuchtröhren und am weiteren Verarbeitungspfad ändert sich
dadurch nichts.

\subsection{Protokoll-Abstraktion (Internes Datenformat)}
\label{subsec:internes-protokoll}

Um die unterschiedlichen externen Eingabemethoden (lokales UI, DMX, Art-Net) zu harmonisieren, überführt die Systemarchitektur 
jegliche Eingaben stets in normierte interne Datenstrukturen (Data Transfer Objects), noch bevor sie verarbeitet oder weitergeleitet werden. 
Das Konzept zielt darauf ab, die physikalische Übertragungsebene von der darstellenden LED-Logik vollständig zu entkoppeln.
Durch die Kapselung in einen Transport-Frame, welcher stets eine Metainformation über die Startadresse mitführt, 
lassen sich DMX-Universen gezielt in kleinere Segmente fragmentieren. 
Dadurch muss nicht das gesamte Universum über die Bandbreiten-limitierte Funkschnittstelle übertragen werden, 
sondern lediglich jener Payload-Sektor, den die adressierten Röhren tatsächlich verarbeiten.

\section{Datenfluss und Signalverarbeitung}
\label{sec:datenfluss-und-signalverarbeitung}

Die Verarbeitung der Steuerdaten folgt unterschiedlichen Pfaden je nach Betriebsmodus. 
In diesem Abschnitt werden die End-to-End-Datenpfade, die Latenzcharakteristiken und die 
Synchronisationsmechanismen beschrieben.

\subsection{End-to-End-Datenpfade}
\label{subsec:end-to-end-datenpfade}

Der Datenfluss im System lässt sich entsprechend der Betriebsmodi in unterschiedliche Kanäle unterteilen:

\subsubsection{Bridge -- Master-Modus}

Im Master-Modus erzeugt die Bridge den Lichtzustand selbst. Aus den am Bedienmenü
gewählten Parametern entsteht fortlaufend ein Steuerdatensatz, der in das interne
Transportformat gekapselt und per Broadcast an alle Röhren verteilt wird. Die Röhren
werten den für sie bestimmten Abschnitt aus und setzen ihn unmittelbar in Licht um. Ein
externes Steuersignal ist an keiner Stelle des Pfades beteiligt.

\subsubsection{Bridge -- DMX-Modus}

Im DMX-Modus fungiert die Bridge als Gateway zwischen DMX-Strecke und Funkverbindung. Das
eingehende Universum wird über die RS-485-Schnittstelle empfangen, vollständig gepuffert
und anschließend auf denjenigen Adressbereich reduziert, den die angesteuerten Röhren
tatsächlich auswerten. Die Größe des übertragenen Pakets wächst dabei linear mit der
Anzahl der Röhren, da je Röhre vier Steuerbytes vorgesehen sind. Jede Röhre entnimmt dem
Broadcast den ihrer Startadresse zugeordneten Abschnitt.

\subsubsection{Leuchtröhre -- Standalone-Modus}

Ohne Verbindung zur Bridge erzeugt die Röhre den Lichtzustand aus den lokal gewählten
Parametern. Der Datenpfad verläuft vollständig innerhalb des Geräts, von der
Menüeingabe über die Lichterzeugung bis zur Ansteuerung des LED-Strips.

\subsubsection{Leuchtröhre -- DMX-Modus}

Im DMX-Modus ist der Empfang bewusst vom Ausgabezyklus entkoppelt: Eingehende Funkpakete
werden asynchron entgegengenommen und zwischengespeichert, während die Lichterzeugung
den jeweils aktuellen Pufferinhalt zyklisch ausliest. Diese Trennung stellt sicher, dass
der Empfang die Ausgabe nicht blockiert und umgekehrt keine Pakete verloren gehen, die
zwischen zwei Ausgabezyklen eintreffen.

\subsection{Datenpaketformate}
\label{subsec:datenpaketformate}

Auf Architekturebene werden zwei Datenkonzepte unterschieden, deren konkrete
speichertechnische Repräsentation Kapitel~\ref{chap:implementierung} beschreibt. Der
Steuerungsdatensatz fasst die Parameter einer einzelnen Röhre zusammen und ist damit die
kleinste adressierbare Einheit. Er wird im Master-Modus wie im DMX-Modus verwendet. Das
Transportformat kapselt eine Folge solcher Datensätze für die drahtlose Übertragung und
führt dabei die Startadresse des übertragenen Ausschnitts mit. Erst diese
Metainformation erlaubt es, statt des vollständigen Universums nur den tatsächlich
benötigten Ausschnitt zu übertragen.

\subsection{Latenzcharakteristiken}
\label{subsec:latenzcharakteristiken}

Die Systemlatenz von der Signaleingabe zur Lichtausgabe wird durch die Summierung 
folgender Teilschritte definiert:

\subsubsection{Bridge-Seite}

\begin{itemize}
    \item \textbf{Signal-Empfang und Decodierung:} Zeitaufwand für das physikalische Einlesen 
    des externen Protokolls (abhängig von der Bus-Baudrate des DMX- oder Netzwerk-Art-Net-Signals).
    \item \textbf{Pufferung und Datenformatierung:} Interne Verarbeitungszeit zur Konvertierung in das Systemprotokoll.
    \item \textbf{Funkübertragung:} Die Ausbreitungs- und Übertragungszeit über den drahtlosen Kanal zur Röhre.
\end{itemize}

\subsubsection{Röhren-Seite}

\begin{itemize}
    \item \textbf{Funksignal-Empfang:} Zeit für die Signalerkennung und Bereitstellung im Speicher.
    \item \textbf{Daten-Abfrage:} Dauer bis zur zyklischen Verarbeitung der bereitgestellten Daten durch die Lichterzeugungslogik.
    \item \textbf{LED-Refresh:} Dauer zur physikalischen Ansteuerung der LED-Hardware.
\end{itemize}

Das Systemarchitektur-Design stellt sicher, dass die Anforderungen an reaktive Beleuchtung 
(Abschnitt~\ref{subsec:echtzeitverhalten}) prinzipiell erfüllt werden können. 
Konkrete Implementierungsdetails und gemessene Zeiten sind Kapitel~\ref{chap:implementierung} 
und \ref{chap:evaluierung} zu entnehmen.

\subsection{Pufferstrategie und Datenaktualisierung}
\label{subsec:pufferstrategie}

Für die drahtlose Übertragung gilt eine Overwrite-Strategie nach dem Prinzip
\textit{Latest Data Only}: Ein eintreffendes Paket überschreibt den vorhandenen
Pufferinhalt unmittelbar, ohne dass ältere Stände aufbewahrt werden. Für Steuerdaten
einer Beleuchtung ist dies die angemessene Wahl, denn ein überholter Lichtzustand hat
keinen Wert mehr, sobald ein neuerer vorliegt. Die Entscheidung hat zwei Folgen, die
unmittelbar auf die Anforderungen einzahlen: Zu jedem Ausgabezyklus liegt stets der
aktuellste verfügbare Wert an, und ein verlorenes Paket führt nicht zu einem Ausfall,
sondern lediglich dazu, dass der zuletzt empfangene Zustand länger gehalten wird. Das in
Abschnitt~\ref{subsec:zuverlaessigkeit} geforderte definierte Verhalten bei
Verbindungsverlust ergibt sich damit unmittelbar aus der Pufferstrategie und erfordert
keine gesonderte Fehlerbehandlung.

Auf der Eingangsseite der Bridge werden dagegen vollständige Universen gepuffert, da ein
DMX-Frame erst nach seinem Ende vollständig ausgewertet werden kann. Eingehende Frames
werden strukturell geprüft, bevor der für die Röhren relevante Adressbereich entnommen
wird. Der Empfang über Art-Net ist vom Ausgabezyklus entkoppelt: Netzwerkpakete werden
asynchron entgegengenommen und zwischengespeichert, sodass sie dem Ausgabetakt ohne
zusätzlichen Jitter zur Verfügung stehen.

\subsection{Synchronisation mehrerer Röhren}
\label{subsec:synchronisation-roehem}

Um eine gleichzeitige Lichtausgabe bei verteilten Röhren zu gewährleisten, kombiniert 
die Architektur folgende Ansätze, anstatt auf aufwändige Zeitsynchronisationsprotokolle zurückzugreifen:

\begin{itemize}
    \item \textbf{Broadcast-Verteilung:} Dieser Ansatz übernimmt den Grundgedanken der DMX-Topologie.
    Das Leitsignal wird simultan an alle Empfangsknoten gesendet, 
    sodass die logische Anweisung an allen Röhren innerhalb desselben Übertragungsfensters am Receiver anliegt.
    
    \item \textbf{Logische Adressierungsschemata:} Die Broadcast-Frames bündeln die Informationen für mehrere Geräte. 
    Jedes Endgerät extrahiert über eine feste Adresszuweisung nur den für sich relevanten Datenblock.
    
    \item \textbf{Dezentrale Autonomie:} Lokal arbeiten die Geräte asynchron mit eigenen Refresh-Zyklen. 
    Die Ausführungsintervalle sind hierbei jedoch so kurz gewählt, dass visuelle Laufzeitunterschiede 
    zwischen Knotenpunkten weit unterhalb der physiologischen menschlichen Wahrnehmungsschwelle für Bewegungen (24 Hz also ca. 42 ms) bleiben \cite{fujii2018,ramunae2025}.
\end{itemize}

Diese Architektur ermöglicht eine dezentrale, eventgesteuerte Verarbeitung ohne zusätzliche Synchronisationsprotokolle 
und behält damit Einfachheit und Zuverlässigkeit bei.

\section{Konfiguration und Bedienkonzept}
\label{sec:konfiguration-und-bedienkonzept}

Bridge und Leuchtröhren werden ausschließlich am Gerät konfiguriert, ohne zusätzliche
Software und ohne Netzwerkzugang. Beide Gerätetypen verwenden dafür dasselbe
Bedienkonzept und dieselbe Kombination aus monochromem OLED-Display und drei Tastern,
sodass sich die Bedienung nicht unterscheidet, gleich welches Gerät der Anwender vor sich
hat. Die Navigation ist zweistufig aufgebaut: Die erste Ebene führt durch die verfügbaren
Parameter, die zweite dient deren Bearbeitung. Die konkrete Umsetzung einschließlich
Eingabeerfassung, Anzeige und Speicherung beschreibt
Abschnitt~\ref{subsec:menu}.

Architektonisch bedeutsam ist, dass der Parametersatz nicht fest vorgegeben ist, sondern
vom aktiven Betriebsmodus abhängt. Angezeigt werden ausschließlich die im jeweiligen
Modus wirksamen Einstellungen, was die Bedienung auf das Notwendige reduziert. Die
Moduswahl selbst ist davon ausgenommen und bleibt stets erreichbar. Daraus ergeben sich
die folgenden Parametersätze:

\begin{itemize}
    \item \textbf{Standalone-Modus (Leuchtröhre):} Effektauswahl und Farbwahl.
    \item \textbf{Master-Modus (Bridge):} Effektauswahl, Farbwahl, Anzahl der
          angesteuerten Leuchtröhren sowie Funkkanal.
    \item \textbf{DMX-Modus:} DMX-Startadresse der Leuchtröhre sowie Funkkanal.
    \item \textbf{Art-Net-Betrieb:} zusätzlich die Netzwerkkonfiguration der Bridge
          (IP-Adresse, DHCP-Aktivierung sowie Art-Net-Netz, Subnetz und Universum).
\end{itemize}

Sämtliche Werte werden persistent im nichtflüchtigen Speicher des Mikrocontrollers
abgelegt und beim Systemstart automatisch geladen. Die Geräte sind damit nach einer
Spannungsunterbrechung ohne erneute Konfiguration betriebsbereit, eine Anforderung, die
sich unmittelbar aus dem Veranstaltungsbetrieb ergibt
(Abschnitt~\ref{subsec:benutzerfreundlichkeit}).

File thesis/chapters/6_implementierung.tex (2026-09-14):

\chapter{Implementierung}
\label{chap:implementierung}

In diesem Kapitel werden die Details der Software- und Hardware-Implementierung 
des LED-Röhrensystems beschrieben. Es werden die Entwicklungsumgebung, 
die Projektstruktur, die Datenmodelle, die gemeinsamen Softwarekomponenten 
sowie die spezifischen Implementierungen für Bridge- und Tube-Firmware erläutert. 
Abschließend wird das Hardware-Design mit Fokus auf die Leiterplatten 
und den mechanischen Aufbau vorgestellt.

\section{Entwicklungsumgebung und Projektstruktur}
\label{sec:entwicklungsumgebung}

Die Firmware wurde mit PlatformIO als Build- und
Projektverwaltungssystem unter Verwendung des Arduino-Frameworks für
ESP32 entwickelt. Die Projektkonfiguration definiert zwei
Zielumgebungen, die unterschiedliche Hardwareplattformen adressieren:
\texttt{led\_tube} für ein Seeed XIAO ESP32-S3 sowie \texttt{bridge}
für ein ESP32 DevKitC. Beide Umgebungen teilen sich eine gemeinsame
Basiskonfiguration (Plattform, Framework, Monitorrate und
Bibliotheksabhängigkeiten), wodurch ein konsistenter Build-Prozess für
beide Gerätetypen sichergestellt wird.

Die Trennung zwischen Röhren- und Bridge-Firmware erfolgt über
bedingte Kompilierung mittels Präprozessormakro \texttt{DEVICE\_MODE}.
Der jeweilige Wert wird build-seitig gesetzt
(\texttt{-D DEVICE\_MODE=0} für Tube, \texttt{-D DEVICE\_MODE=1} für
Bridge) und in der Quellbasis über symbolische Konstanten ausgewertet.
Dadurch werden hardwarespezifische Pinbelegungen, Treiber und
Laufzeitpfade bereits zur Compile-Zeit selektiert. Dieses Vorgehen
reduziert Laufzeitverzweigungen und vermeidet die Einbindung nicht
benötigter Komponenten in das jeweilige Ziel-Binary.

Die zentrale Ablaufsteuerung ist in einer gemeinsamen
\texttt{setup()}/\texttt{loop()}-Struktur organisiert. Gemeinsame
Funktionen wie Menübedienung und ESP-NOW-Kanalsynchronisierung werden
in beiden Gerätevarianten ausgeführt, bridge-spezifische Funktionen
(DMX-Eingang und Generierung der Tube-Payload) werden ausschließlich
im Bridge-Build kompiliert. Innerhalb der Hauptschleife wählt eine
\texttt{switch}-Verzweigung anhand des im Menü gesetzten Betriebsmodus
den jeweils aktiven Datenpfad aus.

Die externen Bibliotheken umfassen insbesondere \texttt{FastLED}
(LED-Ansteuerung), \texttt{esp\_dmx} (DMX512-Empfang), \texttt{Ethernet}
und \texttt{ArtNet} (Art-Net-Empfang über das W5500-Modul) sowie
\texttt{Adafruit GFX}/\texttt{Adafruit SSD1306} (OLED-Ausgabe). Die
Abhängigkeiten sind in der Projektkonfiguration explizit versioniert,
um reproduzierbare Builds zu gewährleisten.

\section{Datenmodell und Paketformate}
\label{sec:datenmodell}

Der Datenaustausch zwischen den Softwarekomponenten basiert auf zwei
klar abgegrenzten DTO-Strukturen (\textit{Data Transfer Objects}).
Diese Trennung ermöglicht eine einheitliche Schnittstelle zwischen dem
DMX-Eingang, der internen Effektlogik und der Ausgabe an die
LED-Controller. Die Formatwahl folgt dem Ziel, einerseits die
Funkübertragung kompakt zu halten und andererseits ausreichend Struktur
für unterschiedliche Betriebsarten bereitzustellen.

\subsection{TubeInput}
\label{subsec:tubeinput}

\texttt{TubeInput} beschreibt den Steuerzustand einer einzelnen Röhre
und umfasst vier Byte: Effektkennung sowie RGB-Werte. Das Format ist auf effektbasierte Ansteuerung
ausgelegt und dient als kleinstes semantisches Steuerobjekt im System.
Durch die feste Feldreihenfolge kann die Struktur ohne zusätzliche
Serialisierung direkt aus empfangenen Bytefolgen rekonstruiert werden.

\subsection{DmxFrame}
\label{subsec:dmxframe}

\texttt{DmxFrame} bildet den Transportrahmen für
drahtlose Übertragung. Die Struktur enthält ein Größenfeld
(\texttt{size}), ein Adressfeld (\texttt{start\_address}) sowie ein
Nutzdatenarray mit bis zu 240 Byte. Die Obergrenze der Nutzdaten
orientiert sich an der Paketgröße von ESP-NOW, die in der ersten
Generation des Protokolls 250 Byte beträgt
(Abschnitt~\ref{subsec:espnow-protokoll}). Die verbleibenden zehn Byte
stehen für den Rahmen und dessen beide Kopfbyte zur Verfügung. Beide
Kopffelder werden ausgewertet: \texttt{size} begrenzt die übertragenen
und verarbeiteten Daten, \texttt{start\_address} bildet die Grundlage
der im folgenden Abschnitt beschriebenen Offsetberechnung.

Im Master-Betrieb der Bridge wird die Nutzlast deterministisch
aufgebaut: Für jede der \(n\) angesteuerten Röhren werden vier
aufeinanderfolgende Byte abgelegt, bestehend aus Effektkennung sowie
den RGB-Werten (\texttt{Effekt}, \texttt{R}, \texttt{G}, \texttt{B}).
Ein zusätzlicher globaler Header wird in dieser Betriebsart nicht
vorangestellt, sodass sich eine Payload-Länge von 4n
Byte ergibt. Das Größenfeld wird entsprechend auf \(4n\) gesetzt und das
Adressfeld auf den Startwert~\texttt{1}. Die feste Datensatzlänge von
vier Byte pro Röhre vereinfacht die Indexberechnung und ermöglicht eine
konstante Zugriffskomplexität. Abbildung~\ref{fig:dmxframe-layout} zeigt
den resultierenden Aufbau eines Frames.

\begin{figure}[H]
    \centering
    \begin{tikzpicture}[x=1cm, y=1cm,
        byte/.style    = {draw, minimum height=0.9cm, minimum width=1.25cm,
                          align=center, font=\footnotesize, inner sep=1pt},
        kopf/.style    = {byte, fill=black!12, minimum width=2.0cm},
        nutz/.style    = {byte, fill=black!3},
        klammer/.style = {decorate, decoration={brace, amplitude=4pt, mirror}},
        klammero/.style= {decorate, decoration={brace, amplitude=4pt}},
        note/.style    = {font=\footnotesize, align=center}]

        \node[kopf] (size) at (0,0) {\texttt{size}};
        \node[kopf, right=0pt of size] (addr) {\texttt{start\_}\\\texttt{address}};

        \node[nutz, right=0pt of addr] (e1) {Effekt};
        \node[nutz, right=0pt of e1]   (r1) {R};
        \node[nutz, right=0pt of r1]   (g1) {G};
        \node[nutz, right=0pt of g1]   (b1) {B};

        \node[byte, draw=none, minimum width=0.9cm, right=0pt of b1] (luecke) {$\cdots$};

        \node[nutz, right=0pt of luecke] (en) {Effekt};
        \node[nutz, right=0pt of en]     (rn) {R};
        \node[nutz, right=0pt of rn]     (gn) {G};
        \node[nutz, right=0pt of gn]     (bn) {B};

        \draw[klammero] (e1.north west) -- (bn.north east)
            node[note, midway, above=6pt] {Nutzdaten: $4n$ Byte, höchstens 240\,Byte};

        \draw[klammer] (size.south west) -- (addr.south east)
            node[note, midway, below=6pt] {Kopf\\2\,Byte};
        \draw[klammer] (e1.south west) -- (b1.south east)
            node[note, midway, below=6pt] {Röhre~1\\Adresse~1};
        \draw[klammer] (en.south west) -- (bn.south east)
            node[note, midway, below=6pt] {Röhre~$n$\\Adresse~$4n-3$};
    \end{tikzpicture}
    \caption{Aufbau eines \texttt{DmxFrame} im Master-Betrieb. Auf die beiden Kopfbyte
        folgt je Röhre ein Block fester Länge. Aus dieser Regelmäßigkeit ergibt sich die
        im folgenden Abschnitt beschriebene Offsetberechnung ohne dynamisches Parsen.}
    \label{fig:dmxframe-layout}
\end{figure}

\subsection{Adressierungsschema}
\label{subsec:adressierung}

Die Datenadressierung erfolgt paketintern über einen byteweisen
Offsetzugriff in Anlehnung an die DMX-Kanaladressierung. Jeder
\texttt{DmxFrame} führt mit \texttt{start\_address} die DMX-Adresse des
ersten Nutzdatenbytes mit. Eine empfangende Röhre berechnet aus ihrer
konfigurierten Adresse den relativen Offset als Differenz von
Geräteadresse und Frame-Startadresse und liest ab dieser Position vier
Byte als \texttt{TubeInput} aus. Vor dem Zugriff wird geprüft, dass der
Offset innerhalb der übertragenen Nutzdatenlänge liegt. Andernfalls wird
der Lesevorgang verworfen. Da die Master-Nutzlast je Röhre einen Block
von vier Byte belegt, werden Geräteadressen praktisch in Schritten von
vier vergeben. Dieses Schema erlaubt einen einfachen, indexbasierten
Zugriff ohne dynamische Parsing-Logik.

\section{Gemeinsame Softwarekomponenten}
\label{sec:gemeinsame-komponenten}

\subsection{Menü- und Bediensystem}
\label{subsec:menu}

Das Menü- und Bediensystem ist als geräteübergreifende Komponente
implementiert und kapselt die Erfassung der Benutzereingaben, die
Darstellung auf dem OLED-Display sowie die persistente Speicherung der
Konfiguration. Die Bedienung erfolgt über drei Taster (UP, DOWN,
ENTER), deren Betätigung über Hardware-Interrupts erfasst wird. 
Die fallende Flanke der mit internem Pull-Up beschalteten Eingänge 
löst die jeweilige ISR (\textit{Interrupt Service Routines}) aus, wodurch die
Eingabeverarbeitung nicht-blockierend in den Programmablauf integriert
ist. Um mechanisches Prellen zu unterdrücken, verwirft eine
Entprellroutine Auslösungen, die innerhalb einer Sperrzeit von 200~ms
nach der letzten gültigen Betätigung auftreten.

Für die fortlaufende Werteänderung bei gehaltener Taste ist eine
Autoincrement-Funktion realisiert: Wird ein Taster länger als 1000~ms
gehalten, wiederholt die Hauptschleife die zugehörige Aktion in
Intervallen von 50~ms. Da die ISRs ausschließlich die fallende Flanke
erfassen, wird das Loslassen der Taster durch zyklisches Abfragen der
Pin-Zustände in der Hauptschleife erkannt.

Die Menüeinträge sind über eine Klassenhierarchie mit gemeinsamer
Basisklasse \texttt{MenuItem} typisiert. Numerische Parameter
(\texttt{NumericMenuItem}) werden über ein Wertintervall mit
Überlaufverhalten definiert, Auswahlparameter
(\texttt{CategoryMenuItem}) bilden benannte Optionen auf interne Werte
ab, Knotenelemente (\texttt{MenuNode}) ermöglichen den Aufbau
hierarchischer Untermenüs und \texttt{BackMenuItem} dient als Rücksprung
aus einem Untermenü. Da \texttt{MenuNode} selbst wieder Zeiger auf
\texttt{MenuItem}-Objekte hält, lassen sich Untermenüs beliebig
schachteln, ohne dass die Navigationslogik die konkreten Eintragstypen
kennen muss (Abbildung~\ref{fig:menu-klassen}). Die Navigation zwischen
den Menüebenen wird über einen Stapelspeicher mit begrenzter Tiefe
verwaltet. Das Bediensystem unterscheidet einen Navigations- und einen
Bearbeitungsmodus, zwischen denen die ENTER-Taste umschaltet.

\begin{figure}[H]
    \centering
    \begin{tikzpicture}[x=1cm, y=1cm,
        klasse/.style = {archbox, text width=3.0cm, fill=black!3, minimum height=1.7cm},
        basis/.style  = {archbox, text width=4.6cm, fill=black!12, thick},
        erbt/.style   = {-{Triangle[open, length=3mm, width=3mm]}, thick},
        haelt/.style  = {{Diamond[open, length=2.6mm, width=2.0mm]}-{Latex[length=2mm]},
                         thick, dashed}]

        \node[basis] (menu) at (0.1,2.2)
            {\textbf{\texttt{Menu}}\\[2pt]\footnotesize \texttt{build\_menu\_tree()},
             Navigationsstapel, NVS-Zugriff};
        \node[basis] (item) at (0.1,0)
            {\textbf{\texttt{MenuItem}}\\[2pt]\footnotesize \texttt{increment()},
             \texttt{decrement()}, \texttt{get\_display\_value()}, \texttt{is\_node()}};

        \node[klasse] (num)  at (-5.0,-2.7) {\texttt{Numeric-}\\\texttt{MenuItem}\\[2pt]\footnotesize Wertintervall mit Überlauf};
        \node[klasse] (cat)  at (-1.6,-2.7) {\texttt{Category-}\\\texttt{MenuItem}\\[2pt]\footnotesize benannte Optionen};
        \node[klasse] (back) at ( 1.8,-2.7) {\texttt{BackMenuItem}\\[2pt]\footnotesize Rücksprung};
        \node[klasse] (nod)  at ( 5.2,-2.7) {\texttt{MenuNode}\\[2pt]\footnotesize Untermenü mit Kindliste};

        % Vererbungsbaum mit gemeinsamem Stamm
        \coordinate (stamm) at (0.1,-1.5);
        \draw[thick] (-5.0,-1.5) -- (5.2,-1.5);
        \foreach \k in {num,cat,back,nod} \draw[thick] (\k.north) -- (\k.north |- stamm);
        \draw[erbt] (stamm) -- (item.south);

        % MenuNode hält selbst wieder MenuItem-Zeiger (Kompositum)
        \draw[haelt] (nod.east) -- (7.4,-2.7) -- (7.4,0) -- (item.east);
        \node[beschr, anchor=west] at (7.5,-1.6) {\texttt{MenuItem**}};

        \draw[link] (menu.south) -- (item.north)
            node[beschr, midway, right=1mm] {baut und durchläuft den Baum};
    \end{tikzpicture}
    \caption{Klassenstruktur des Bediensystems. Alle Eintragstypen leiten von
        \texttt{MenuItem} ab \texttt{MenuNode} hält seinerseits eine Liste solcher
        Einträge, wodurch die Menüstruktur rekursiv aufgebaut ist und
        \texttt{Menu} sie unabhängig vom konkreten Typ verwalten kann.}
    \label{fig:menu-klassen}
\end{figure}

Die verfügbaren Einträge werden modusabhängig zur Laufzeit aufgebaut:
Bei jedem Wechsel des Betriebsmodus erzeugt die Methode
\texttt{build\_menu\_tree()} die für den aktiven Modus relevante Auswahl
an Einträgen neu. Dadurch werden dem Bediener ausschließlich die im
jeweiligen Modus wirksamen Parameter angezeigt.

Die Anzeige erfolgt auf einem monochromen SSD1306-OLED-Display, das über
I2C mit einer Taktrate von 400~kHz angebunden ist. Um die Buslast gering
zu halten und die Auslastung des Mikrocontrollers zu minimieren, 
wird das Display flag-gesteuert neu gezeichnet, d.\,h. eine
Neuzeichnung erfolgt nur nach einer tatsächlichen Zustandsänderung. Im
Bearbeitungsmodus wird der aktive Eintrag zur visuellen Abgrenzung
invertiert dargestellt.

Sämtliche Konfigurationswerte werden im nichtflüchtigen Speicher (NVS)
des ESP32 abgelegt, wofür die \texttt{Preferences}-Bibliothek unter einem
gemeinsamen Namensraum genutzt wird. Beim Systemstart werden die
gespeicherten Werte geladen, sodass die zuletzt gewählte Konfiguration
ohne erneute Eingabe verfügbar ist. Um Schreibzugriffe aus dem
Interrupt-Kontext herauszuhalten, wird eine Wertänderung in der ISR
lediglich vorgemerkt. Der eigentliche Schreibvorgang in den
Flash-Speicher wird anschließend in der Hauptschleife ausgeführt.

\subsection{LED-Steuerung und Effekte}
\label{subsec:led-steuerung}

Die LED-Steuerung kapselt die \texttt{FastLED}-Bibliothek, welche die
zeitkritische Ansteuerung der adressierbaren LEDs übernimmt. Die
LED-Kette wird zur Initialisierung mit \texttt{NUM\_LEDS} Pixeln und
festgelegter Farbreihenfolge an einem dedizierten Daten-Pin registriert.
Die Übergabe der Eingangsdaten erfolgt über mehrfach überladene
\texttt{set\_input()}-Methoden, die einen Effektdatensatz 
(\texttt{TubeInput}) für den drahtlosen Empfang entgegennehmen 
und in den internen Zustand überführen.

Die zyklisch aufgerufene Methode \texttt{handle()} wählt anhand der gespeicherten Effektkennung den
auszuführenden Effekt aus und schreibt das Ergebnis abschließend über
\texttt{FastLED.show()} an die Hardware. Die implementierten
Effekte umfassen statische Farbdarstellung und Helligkeitsverläufe,
helligkeitsmodulierte Pulseffekte, positions- bzw. laufzeitbasierte
Lauflichter, Lauflichter mit exponentiell abklingendem Nachleuchten,
simulationsbasierte Effekte wie Feuer, Perlin-Rauschen und einen
springenden Ball sowie Strobo-, Blitz-, Funkel- und Regenbogeneffekte.
Helligkeitsverläufe werden über eine exponentielle Kennlinie (vierte
Potenz der normierten Helligkeit) berechnet, um weiche, visuell
gleichmäßige Helligkeitsübergänge zu erzeugen.

Die Effekte sind als reine Funktionen der verstrichenen Zeit
formuliert und nicht als Funktionen der Aufrufhäufigkeit. Die
Ablaufgeschwindigkeit ist dadurch unabhängig von der Schleifenrate,
die je nach Displayaktualisierung, Funkverkehr und Betriebsmodus
schwankt.

\subsection{Drahtlose Kommunikation (ESP-NOW)}
\label{subsec:espnow}

Die drahtlose Kommunikation ist im \texttt{WirelessDmxController}
gekapselt, der das ESP-NOW-Protokoll von Espressif verwendet. Zur
Initialisierung wird die WLAN-Schnittstelle in den Station-Modus
versetzt, die bestehende Access-Point-Funktion deaktiviert und ESP-NOW
initialisiert. Anschließend wird ein Empfangs-Callback registriert.
Adressiert wird ausschließlich über die Broadcast-MAC-Adresse
\texttt{FF:FF:FF:FF:FF:FF}, sodass alle Röhren in Reichweite gleichzeitig
erreicht werden.

Um die für den ESP32 maximal mögliche Sendeleistung von 20~dBm auszuschöpfen, 
muss keine Sendeleistungskonfiguration vorgenommen werden, da der ESP32 diese 
Leistung standardmäßig verwendet und nur bei gewünschter Drosselung explizit 
konfiguriert werden kann \cite{espressif_esp32_tx}.

Der im Menü wählbare logische Kanal (1 bis 3) wird über eine feste
Zuordnung auf die WLAN-Kanäle 1, 5 und 10 abgebildet. Diese Spreizung
verringert die gegenseitige Beeinflussung mehrerer parallel betriebener
Systeme. Ein Kanalwechsel wird zur Laufzeit über
\texttt{sync\_channel()} in der Hauptschleife erkannt und nur bei einer
tatsächlichen Änderung angewendet.

Der Empfang erfolgt im Interrupt-Kontext des Funktreibers: Der
registrierte Callback kopiert das eingegangene Paket unmittelbar in einen
internen \texttt{DmxFrame}-Puffer (Overwrite-Strategie), nachdem die
Rahmenlänge sowie die Konsistenz von Header und Nutzdatenlänge geprüft
wurden. Da der Callback statisch ist, wird der Zugriff auf die
Instanzdaten über ein Singleton-Muster hergestellt. Auf der Sendeseite
überträgt \texttt{write()} den Frame als Broadcast, wobei neben den
Nutzdaten die beiden Headerbyte (Größe und Startadresse) mitgesendet
werden.

\subsection{Nebenläufigkeit und Kernverteilung}
\label{subsec:nebenlaeufigkeit}

Ein wesentliches Entwurfsziel der Datenpfade ist die Entkopplung der
zeitkritischen Signalein- und -ausgabe von der zyklischen
Effektberechnung in der Hauptschleife. Hierzu werden zwei Mechanismen
genutzt: die interruptgesteuerte, asynchrone Verarbeitung der
Schnittstellen sowie die Verteilung der Arbeitslast auf die beiden Kerne
des ESP32. Abbildung~\ref{fig:datenpfad} zeigt den daraus folgenden
Datenpfad vom DMX-Eingang der Bridge bis zur Lichtausgabe der Röhre.

Der ESP32 ist ein Dual-Core-Mikrocontroller. Unter dem
Arduino-/FreeRTOS-Laufzeitsystem wird die Hauptschleife als
eigenständiger Task ausgeführt, der standardmäßig dem Applikationskern
zugeordnet ist, während der WLAN-Protokollstack, über den die
ESP-NOW-Übertragung abgewickelt wird, vom Laufzeitsystem auf dem
zweiten Kern (Protokollkern) betrieben wird. Das Senden und Empfangen
der Funkpakete erfolgt dadurch nebenläufig zur Effektberechnung und
blockiert die Hauptschleife nicht. Auf der Bridge kann somit der
Protokollkern bereits ein Funkpaket aussenden, während der
Applikationskern den nächsten DMX-Ausschnitt aufbereitet. Auf der Röhre
nimmt der Funkstack ein eingehendes Paket entgegen, ohne den laufenden
Render-Zyklus zu unterbrechen.

Der Empfang der ESP-NOW-Pakete wird über den registrierten Callback
realisiert, der asynchron aus dem Kontext des Funktreibers aufgerufen
wird. Da Funkempfang und Hauptschleife auf diese
Weise entkoppelt sind, dient der bereits beschriebene Overwrite-Puffer
als Übergabepunkt zwischen beiden Ausführungssträngen: Der Callback
aktualisiert den Puffer, sobald ein Paket eintrifft, und die
Hauptschleife liest stets den zuletzt gültigen Zustand.

Der DMX512-Empfang folgt demselben Prinzip der Entkopplung, ist jedoch
interruptgesteuert umgesetzt: Die \texttt{esp\_dmx}-Bibliothek erfasst
ein vollständiges Universum im Hintergrund über die UART-Hardware und
deren Interrupt-Routine. Die zeitkritische Erfassung des Bussignals ist
damit von der Ausführungszeit der Hauptschleife unabhängig. Diese pollt
den Treiber lediglich und entnimmt das fertig gepufferte Universum. Nach
demselben Muster werden die Benutzereingaben über Taster-Interrupts
erfasst und Flash-Schreibzugriffe aus dem Interrupt-Kontext heraus in die
Hauptschleife verlagert (vgl. Abschnitt~\ref{subsec:menu}), sodass die
Hauptschleife durchgängig kurze und gleichmäßige Zykluszeiten beibehält.

\begin{figure}[H]
    \centering
    \begin{tikzpicture}[x=1cm, y=1cm,
        stufe/.style  = {archbox, text width=2.6cm},
        async/.style  = {stufe, fill=black!12, thick},
        sync/.style   = {stufe, fill=black!3},
        puffer/.style = {stufe, draw, dashed, thick, fill=white}]

        % --- Bridge ---
        \node[async]  (b1) at (0,0)      {UART-ISR\\[1pt]\footnotesize \texttt{esp\_dmx}};
        \node[puffer] (b2) at (3.6,-1.35){Universumspuffer\\[1pt]\footnotesize im Treiber};
        \node[sync]   (b3) at (7.2,-2.7) {Hauptschleife\\[1pt]\footnotesize Ausschnitt wählen, \texttt{DmxFrame} füllen};
        \node[async]  (b4) at (10.8,0)   {ESP-NOW-Stack\\[1pt]\footnotesize Protokollkern};

        \draw[link] (b1) -- (b2);
        \draw[link] (b2) -- (b3) node[beschr, midway, below left=-1mm] {pollen};
        \draw[link] (b3) -- (b4) node[beschr, midway, right=1mm] {\texttt{write()}};

        \begin{scope}[on background layer]
            \node[huelle, fit=(b1)(b2)(b3)(b4),
                  label={[font=\small\bfseries]above:Bridge}] (hb) {};
        \end{scope}

        % --- Leuchtröhre ---
        \node[async]  (t1) at (0,-6.2)    {Empfangs-Callback\\[1pt]\footnotesize Kontext des ESP-NOW-Treibers};
        \node[puffer] (t2) at (3.6,-7.55) {Overwrite-Puffer\\[1pt]\footnotesize \texttt{DmxFrame}};
        \node[sync]   (t3) at (7.2,-8.9)  {Hauptschleife\\[1pt]\footnotesize Offset, \texttt{TubeInput}};
        \node[sync]   (t4) at (10.8,-8.9) {\texttt{LedController}\\[1pt]\footnotesize \texttt{FastLED.show()}};

        \draw[link] (t1) -- (t2);
        \draw[link] (t2) -- (t3) node[beschr, midway, below left=-1mm] {\texttt{read()}};
        \draw[link] (t3) -- (t4);

        \begin{scope}[on background layer]
            \node[huelle, fit=(t1)(t2)(t3)(t4),
                  label={[font=\small\bfseries]above:Leuchtröhre}] (ht) {};
        \end{scope}

        % --- Funkstrecke ---
        \coordinate (r1) at (13.1,0);
        \coordinate (r2) at (13.1,-4.45);
        \coordinate (r3) at (-2.3,-4.45);
        \coordinate (r4) at (-2.3,-6.2);
        \draw[funk] (b4.east) -- (r1) -- (r2) -- (r3)
            node[beschr, midway, above] {ESP-NOW-Broadcast} -- (r4) -- (t1.west);
    \end{tikzpicture}
    \caption{Datenpfad und Ausführungskontexte. Dunkel hinterlegte Stufen laufen
        asynchron im Interrupt- oder Protokollkontext, hell hinterlegte in der
        Hauptschleife des Applikationskerns. Die beiden gestrichelt gezeichneten Puffer
        sind die einzigen Übergabepunkte zwischen beiden Kontexten. Dadurch blockiert
        weder der Empfang die Effektberechnung noch umgekehrt.}
    \label{fig:datenpfad}
\end{figure}

\section{Bridge-Firmware}
\label{sec:bridge-firmware}

\subsection{Betriebsmodi}
\label{subsec:bridge-modi}

Die Bridge-Firmware stellt zwei Betriebsmodi bereit, zwischen denen im
Menü umgeschaltet wird. Im \textbf{Master-Modus} (Modus~0) erzeugt die
Bridge Farben und Effekte eigenständig und versendet die resultierende
Nutzlast über ESP-NOW an alle Röhren. Im \textbf{Wireless-DMX-Modus}
(Modus~1) empfängt die Bridge ein DMX512-Universum, extrahiert den für
die registrierten Röhren relevanten Adressbereich und leitet diesen als
\texttt{DmxFrame} drahtlos weiter.

Die Quelle des Universums ist dabei nicht auf die kabelgebundene
DMX-Schnittstelle festgelegt: Alternativ kann es über Art-Net von der
Ethernet-Schnittstelle bezogen werden
(Abschnitt~\ref{subsec:artnet-eingang}). Da beide Eingänge dasselbe
Universum liefern, unterscheiden sie sich ausschließlich in der
Empfangsstufe, der weitere Verarbeitungs- und Sendepfad ist identisch.

\subsection{Master-Modus: TubeController und Effektgenerierung}
\label{subsec:tubecontroller}

Im Master-Modus übernimmt der \texttt{TubeController} die eigenständige
Generierung der Lichtzustände. Er verwaltet bis zu \texttt{MAX\_TUBES}
(20) Röhrenobjekte, die jeweils eine Adresse, eine Effektkennung und
einen Farbwert halten. Die im Menü konfigurierte Anzahl tatsächlich
angesteuerter Röhren begrenzt die aktiv beschriebenen Objekte.

Die zeitliche Struktur der Effekte wird durch den \texttt{SoundController}
vorgegeben, der aus einer im Menü einstellbaren Schlagzahl
(\textit{Beats Per Minute}, 60 bis 200) einen Takt ableitet. Hierzu
prüft die Methode \texttt{beat\_from\_bpm()}, ob seit dem letzten Beat
das aus der Schlagzahl berechnete Intervall (\(60000\,\text{ms} /
\text{BPM}\)) verstrichen ist, und erzeugt so ohne Audioeingang einen
periodischen Beat-Indikator. Auf dieser Grundlage werden Farb- und
Effektwechsel rhythmisch synchronisiert. Wahlweise werden Farbe und
Effekt fest aus dem Menü vorgegeben oder automatisch in festen
Intervallen gewechselt.

Die zyklische Methode \texttt{handle()} wählt anhand der aktiven
Effektkennung den Effekt aus, der die Zustände aller Röhrenobjekte setzt.
Anschließend serialisiert \texttt{generate\_payload()} diese Zustände in
das beschriebene Layout von vier Byte pro Röhre. Die Methode
\texttt{get\_payload()} überführt den Puffer in einen \texttt{DmxFrame},
begrenzt die Länge auf die maximale ESP-NOW-Nutzlast und setzt
Größenfeld sowie Startadresse, bevor der Frame über den
\texttt{WirelessDmxController} versendet wird.

\subsection{DMX512-Eingang}
\label{subsec:dmx-eingang}

Der DMX512-Empfang ist im \texttt{DMXController} gekapselt, der die
Bibliothek \texttt{esp\_dmx} zur interrupt-basierten Auswertung der über
einen RS-485-Transceiver eingelesenen Signale nutzt. Die Methode
\texttt{update()} fragt den Treiber mit einem Zeitlimit von 100~ms ab und
übernimmt vollständig empfangene Pakete in einen internen Puffer.

Die Methode \texttt{read(start\_address, num\_tubes)} extrahiert aus
diesem Puffer einen Ausschnitt, dessen Länge sich aus der Anzahl
angesteuerter Röhren multipliziert mit der Datensatzgröße von vier Byte
ergibt. Eine Bereichsprüfung stellt sicher, dass ausschließlich
tatsächlich verfügbare Daten kopiert werden und die maximale Funknutzlast
nicht überschritten wird. Das Ergebnis wird als \texttt{DmxFrame}
bereitgestellt und über ESP-NOW an die Röhren gesendet. Auf diese Weise
wird nicht das gesamte DMX-Universum, sondern lediglich der für die
registrierten Röhren relevante Adressbereich übertragen.

\subsection{Art-Net-Eingang}
\label{subsec:artnet-eingang}

Der Empfang über Art-Net ist im \texttt{ArtNetReceiver} gekapselt, der
das W5500-Ethernet-Modul über SPI anbindet. Vor der Initialisierung der
SPI-Schnittstelle führt \texttt{reset\_w5500()} einen Hardware-Reset des
Moduls über eine dedizierte Reset-Leitung aus, da das Modul andernfalls
nach einem Warmstart des Mikrocontrollers in einem undefinierten Zustand
verbleiben kann. Die Netzwerkkonfiguration erfolgt anschließend über
DHCP, wobei die Zeitbudgets für den Handshake bewusst knapp bemessen
sind: Ist kein DHCP-Server erreichbar, wird der Vorgang abgebrochen und
das Gerät bleibt in den übrigen Betriebsmodi uneingeschränkt verwendbar,
statt beim Start zu blockieren.

Die Adressierung folgt der in Abschnitt~\ref{subsubsec:artnet-protokoll}
beschriebenen Port-Address aus Net, Sub-Net und Universe. Die Methode
\texttt{set\_universe()} prüft die drei Bestandteile gegen ihre
Wertebereiche: Net kleiner als 128, Sub-Net und Universe jeweils
kleiner als 16 und abonniert anschließend genau dieses Universum. Nur
Pakete mit passender Port-Address lösen den registrierten Callback aus,
sodass in einem Netzwerk mit mehreren Universen keine Filterung auf
Anwendungsebene erforderlich ist.

Der Callback wird von der Art-Net-Bibliothek in einem eigenen Task auf
dem Protokollkern ausgeführt, während die Hauptschleife auf dem
Applikationskern läuft. Puffer und zugehörige Längenangabe werden
deshalb gemeinsam innerhalb eines kritischen Abschnitts geschrieben, der
über einen \texttt{portMUX} realisiert ist. Die Hauptschleife liest sie
unter demselben Schutz wieder aus. Damit ist ausgeschlossen, dass ein
Lesevorgang eine Länge sieht, die nicht zum Pufferinhalt passt. Die
Übergabe folgt im Übrigen demselben Muster wie beim Funkempfang
(Abschnitt~\ref{subsec:nebenlaeufigkeit}): Der zuletzt empfangene Stand
überschreibt den vorherigen, ohne dass eine Warteschlange entsteht.

Die Ethernet-Verbindung kann im Veranstaltungsbetrieb auch nachträglich
hergestellt werden. Die Methode \texttt{check\_and\_reinit()} prüft
deshalb zyklisch den Verbindungsstatus und initialisiert den Empfänger
nach, sobald ein Kabel eingesteckt wird. Ein zum Startzeitpunkt fehlendes Netzwerk führt damit
nicht dazu, dass Art-Net bis zum nächsten Neustart unverfügbar bleibt.

Das empfangene Universum wird anschließend wie ein über die
DMX-Schnittstelle eingelesenes behandelt: Aus ihm wird der für die
registrierten Röhren relevante Adressbereich entnommen, in einen
\texttt{DmxFrame} überführt und über ESP-NOW verteilt. Ab dieser Stufe
sind die beiden Eingangswege nicht mehr unterscheidbar, sodass die
Auswahl zwischen kabelgebundenem DMX und Art-Net ausschließlich die
Anbindung an die vorhandene Infrastruktur betrifft.

Die für Art-Net erforderlichen Netzwerkparameter werden über das
Bedienmenü der Bridge gesetzt. Da die IP-Konfiguration aus mehreren
Teilwerten besteht, den vier Bestandteilen der Adresse, der
DHCP-Aktivierung sowie Net, Sub-Net und Universum, ist sie als
verschachteltes Untermenü ausgeführt und nutzt damit die in
Abschnitt~\ref{subsec:menu} beschriebenen Knotenelemente.

\section{Tube-Firmware}
\label{sec:tube-firmware}

\subsection{Betriebsmodi}
\label{subsec:tube-modi}

Die Tube-Firmware stellt zwei Betriebsmodi bereit. Im
\textbf{Standalone-Modus} (Modus~0) werden Farbe und Effekt unmittelbar über
das lokale Menü vorgegeben und als \texttt{CRGB}-Farbe an den
\texttt{LEDController} übergeben. Im \textbf{Wireless-DMX-Modus}
(Modus~1) empfängt die Röhre einen \texttt{DmxFrame} über ESP-NOW und
extrahiert den ihrer Adresse entsprechenden Datenabschnitt, der als
\texttt{TubeInput} an den \texttt{LEDController} weitergegeben wird.

\subsection{Datenempfang und Rendering}
\label{subsec:tube-rendering}

Im drahtlosen Empfang liest die Methode \texttt{read(address)} des
\texttt{WirelessDmxController} aus dem zuletzt empfangenen
\texttt{DmxFrame} den der konfigurierten Adresse entsprechenden Block von
vier Byte aus und gibt diesen als \texttt{TubeInput} zurück. Die Übergabe
an \texttt{set\_input(TubeInput)} setzt Effektkennung und Farbwerte im
\texttt{LEDController}. Die anschließend aufgerufene Methode
\texttt{handle()} führt den aktuell gesetzten Effekt aus und schreibt das
Ergebnis über \texttt{FastLED} an den LED-Strip. Da der Empfangspuffer
nach der Overwrite-Strategie stets den aktuellsten Datenstand vorhält,
führt ein gelegentlicher Paketverlust lediglich zum kurzzeitigen
Beibehalten des letzten Zustands.

\section{Testaufbau zur Zuverlässigkeitsmessung}
\label{sec:testaufbau}

Zur quantitativen Bewertung der drahtlosen Übertragung wurde eine
dedizierte Mess-Firmware entwickelt, die von der eigentlichen
Anwendungsfirmware getrennt ist. Die Messprogramme sind im Verzeichnis
\texttt{test\_programs} abgelegt und werden über eigene
PlatformIO-Umgebungen gebaut, die mittels \texttt{build\_src\_filter}
ausschließlich die jeweils benötigten Quelldateien einbinden. Auf diese
Weise wird der reale \texttt{WirelessDmxController} unverändert in den
Testaufbau übernommen, sodass die Messung die tatsächliche
Übertragungskomponente des Systems erfasst. Die in diesem Abschnitt
beschriebene Implementierung dient der Datenerhebung. Die Auswertung der
Messreihen erfolgt im Rahmen der Evaluierung in
Kapitel~\ref{chap:evaluierung}.

\subsection{Mess-Firmware}
\label{subsec:mess-firmware}

Der Testaufbau besteht aus einem Sender (Bridge) und einem Empfänger
(Röhre). Der Sender überträgt über den \texttt{WirelessDmxController}
\texttt{DmxFrame}-Pakete mit einer Nutzlast von 80~Byte, was der
Ausbaugröße von 20 Röhren zu je vier Kanälen entspricht
(Abschnitt~\ref{subsec:fa-kommunikation}).

Entscheidend für die Aussagekraft der Messung ist, dass Sendetakt und
Nutzdatentakt getrennt geführt werden. Als Nutzdaten dient ein
fortlaufender Sequenzzähler, dessen Wert alle 25~ms erhöht wird und bei
255 überläuft. Das entspricht der angestrebten Aktualisierungsrate von
40~Hz. Unabhängig davon wird alle 5~ms ein Paket ausgesendet, sodass
jeder Sequenzwert nominell fünffach übertragen wird. Damit bildet der
Testaufbau das Verhalten der produktiven Firmware nach, in der die Bridge
den aktuellen Lichtzustand ungedrosselt wiederholt aussendet. Das feste
Sendeintervall dient lediglich der Vergleichbarkeit der Messläufe.

Abbildung~\ref{fig:messtakte} stellt beide Takte gegenüber. Aus der
Trennung folgt die für die Auswertung wesentliche Unterscheidung: Der
Ausfall einzelner Pakete bleibt für die Lichtausgabe folgenlos, solange
je Sequenzwert wenigstens eine Kopie eintrifft. Erst der Ausfall aller
fünf Kopien führt zu einem tatsächlich verlorenen Zustandswechsel.

\begin{figure}[H]
    \centering
    \begin{tikzpicture}[x=1cm, y=1cm,
        puls/.style  = {draw, fill=black!55, minimum width=0.16cm,
                        minimum height=0.6cm, inner sep=0pt},
        fehlt/.style = {draw=black!45, dashed, fill=none, minimum width=0.16cm,
                        minimum height=0.6cm, inner sep=0pt},
        rand/.style  = {draw=black!35, dashed},
        zeile/.style = {font=\footnotesize, align=right, anchor=east}]

        % Sequenzfenster
        \draw[fill=black!8] (0,1.05) rectangle (5,1.65);
        \draw[fill=black!8] (5,1.05) rectangle (10,1.65);
        \node[font=\footnotesize] at (2.5,1.35) {Sequenzwert $n$};
        \node[font=\footnotesize] at (7.5,1.35) {Sequenzwert $n+1$};
        \node[font=\footnotesize] at (10.7,1.35) {$\cdots$};

        % Trennlinien der Sequenzfenster
        \foreach \x in {0,5,10} \draw[rand] (\x,-2.55) -- (\x,1.9);

        % Zeitachse
        \draw[->] (-0.3,0) -- (11.4,0) node[right, font=\footnotesize] {$t$};
        \foreach \x in {0,1,2,3,4,5,6,7,8,9,10} \draw (\x,0.08) -- (\x,-0.08);
        \node[below, font=\footnotesize] at (0,-0.1)  {0};
        \node[below, font=\footnotesize] at (5,-0.1)  {25\,ms};
        \node[below, font=\footnotesize] at (10,-0.1) {50\,ms};

        % Sendetakt: alle 5 ms eine Aussendung
        \foreach \x in {0.5,1.5,2.5,3.5,4.5,5.5,6.5,7.5,8.5,9.5,10.5}
            \node[puls] at (\x,-0.95) {};

        % Empfang: einzelne Kopien fehlen
        \foreach \x in {0.5,1.5,3.5,4.5,8.5,10.5} \node[puls]  at (\x,-2.1) {};
        \foreach \x in {2.5,5.5,6.5,7.5,9.5}      \node[fehlt] at (\x,-2.1) {};

        % Zeilenbeschriftung
        \node[zeile] at (-0.45,1.35)  {Sequenzwert\\(25\,ms)};
        \node[zeile] at (-0.45,-0.95) {Aussendung\\(5\,ms)};
        \node[zeile] at (-0.45,-2.1)  {Empfang};
    \end{tikzpicture}
    \caption{Getrennte Taktung der Mess-Firmware. Je Sequenzwert werden fünf Kopien
        ausgesendet. Im dargestellten Verlauf gehen im ersten Fenster eine und im
        zweiten vier Kopien verloren, ohne dass ein Sequenzwert ausfällt. Als
        Sequenzverlust zählt erst ein Fenster, aus dem keine einzige Kopie eintrifft.}
    \label{fig:messtakte}
\end{figure}

Der Empfänger registriert einen ESP-NOW-Empfangs-Callback und wertet
jedes eingegangene Paket aus. Aus der Zählfolge wird zum einen
rekonstruiert, welche Sequenzwerte vollständig ausgeblieben sind, zum
anderen, wie viele der fünf Aussendungen je Sequenzwert tatsächlich
eingetroffen sind. Die erste Größe beschreibt den für die Lichtausgabe
maßgeblichen Verlust, die zweite die verbleibende Übertragungsreserve.
Zusätzlich werden die Länge der längsten zusammenhängenden Verlustserie,
die mittlere Zwischenankunftszeit aufeinanderfolgender Sequenzwerte und
deren Standardabweichung (Jitter) sowie die Empfangsfeldstärke (RSSI)
erhoben.
Der RSSI-Wert wird über einen im Promiscuous-Modus betriebenen
Paket-Sniffer ermittelt. Da Empfangs-Callback und Hauptschleife
gemeinsam auf die Zählvariablen zugreifen, wird dieser Zugriff über einen
Spinlock synchronisiert. Der Empfänger gibt im Sekundentakt eine
CSV-Zeile aus, die sowohl fenster- als auch laufzeitbezogene Kennzahlen
enthält.

\subsection{Datenerfassung und Auswertung}
\label{subsec:datenerfassung}

Die serielle Ausgabe des Empfängers wird host-seitig über das Skript
\texttt{capture.sh} aufgezeichnet, das den seriellen Port direkt ausliest
und die Aufzeichnung auf eine vorgegebene Dauer begrenzt, während die
Firmware selbst zeitlich unbegrenzt läuft. Die Rohdaten werden unverändert
als CSV abgelegt und nicht nachträglich modifiziert, um die
Reproduzierbarkeit der Auswertung zu gewährleisten.

Die Auswertung erfolgt über das Python-Skript \texttt{analyze.py}, das
jede Rohdatendatei verarbeitet und den Testtyp sowie die Messbedingungen
aus dem Dateinamen ableitet. Unterstützt werden die Testtypen
Paketverlust, Störfestigkeit, Reichweite und Langzeitstabilität, wobei
die Reichweitenmessung zusätzlich zwischen Läufen mit und ohne
Sichtverbindung unterscheidet und beide als getrennte Messreihen
auswertet. Das Skript erzeugt daraus Kennzahltabellen im \LaTeX- und
CSV-Format sowie Diagramme im PDF-Format, die direkt in die Arbeit
eingebunden werden. Berechnet werden die kumulierte und die
fensterbezogene Verlustrate, die mittlere Anzahl empfangener Kopien je
Sequenzwert, die längste Verlustserie, der Jitter sowie die mittlere
Feldstärke. Die Bedeutung dieser Kennzahlen für die Bewertung der
Lichtausgabe wird in Abschnitt~\ref{subsec:metriken} erläutert.

\section{Hardware-Design}
\label{sec:hardware-design}

Das Hardware-Design des Systems umfasst drei Leiterplatten:
das Bridge-PCB, das Tube-PCB sowie die Interface-PCB.
Letztere wird als gemeinsames, identisches Bedienelement sowohl
in der Bridge als auch in der Tube eingesetzt. Im Folgenden
werden zunächst die übergreifenden Fertigungs- und
Entwurfsparameter beschrieben, bevor die einzelnen Baugruppen
sowie die Leistungs-, Funk- und Schutzbeschaltung im Detail
erläutert werden.

\subsection{Leiterplattenfertigung und Entwurfsparameter}
\label{subsec:pcb-fertigung}

Der Schaltplan- und Leiterplattententwurf erfolgte mit dem
Open-Source-Software KiCad. Alle Platinen sind als
zweilagige Leiterplatten mit einer Kupferauflage von 35~µm
(1~oz/ft²) ausgeführt. Fertigung und Bestückung wurden über
den Dienstleister JLCPCB realisiert. Die Bestückung umfasst
eine Mischung aus SMD-Bauteilen der Baugröße 1206, die für
die manuelle Handlötung geeignet sind, sowie bedrahteten
THT-Komponenten an mechanisch belasteten Verbindungen wie
Steckverbindern.

Die Leiterbahnbreiten wurden last- und signalabhängig
ausgelegt. Leistungsleitungen der 12-V-Versorgung sind mit
2~mm Breite ausgeführt, um Ströme bis 4~A bei einer
zulässigen Temperaturerhöhung von 20~K sicher zu führen.
Dieser Wert ergibt sich gemäß IPC-2221 bei einer Kupferdicke
von 35~µm. Bei der umgesetzten Lösung mit 12V LED-Chips werden 
lediglich Ströme bis 2A erwartet. Um den Nachbau mit 5V Chips 
wie den weit verbreiteten WS2812b zu ermöglichen, bei welchen 
höhere Ströme bei gleicher Leistung fließen sind die 
Versorgungsleitungen entsprechend dimensioniert.
Signalleitungen sind mit 0,5~mm ausgeführt, da
dort deutlich geringere Ströme fließen. Alle übrigen
Designregeln orientieren sich an den Herstellervorgaben von
JLCPCB hinsichtlich minimaler Leiterbahnbreite und
minimalem Leiterabstand.

Ein besonderes Entwurfsmerkmal betrifft die Bridge: Deren DMX-Eingang
ist galvanisch vom übrigen Teil der Schaltung getrennt, was sich im
Layout in zwei voneinander abgesetzten Masseflächen niederschlägt. Die
konstruktive Umsetzung dieser Trennung wird in
Abschnitt~\ref{subsec:bridge-pcb} beschrieben.

Der Platinen-Formfaktor wurde an die jeweilige Gehäuse- und
Rohrgeometrie angepasst. Die Programmierung der ESP-Module 
sowie die serielle Diagnoseausgabe erfolgen
über den USB-C-Anschluss der jeweiligen Entwicklungsmodule.

\subsection{Bridge-PCB}
\label{subsec:bridge-pcb}

Die Bridge-Hauptplatine trägt den ESP32 DevKitC als
Mikrocontroller, ein USR-ES1-Ethernet-Modul auf Basis des
W5500-Chips mit SPI-Schnittstelle sowie zwei SN75176BP
RS-485-Transceiver für den DMX-Ein- und -Ausgang. Die
Spannungsversorgung der Bridge erfolgt über den
USB-C-Anschluss des DevKitC-Moduls mit 5~V. Da die Bridge
keine hohen Lastströme liefert, ist die USB-Stromversorgung
für den Betrieb aller angeschlossenen Komponenten ausreichend
dimensioniert. Die boardinternen Kondensatoren des DevKitC
stabilisieren die Versorgungsspannung, sodass kein
zusätzlicher Spannungsregler erforderlich ist.

Der DMX-Eingang ist galvanisch vom Rest der Schaltung
getrennt. Hierzu werden ein 6N137-Optokoppler sowie ein
ADUM1201-Digitalisolator eingesetzt. Die Spannungsversorgung
der galvanisch isolierten Seite erfolgt über einen
TEA1-0505-DC/DC-Wandler, der die Potentialtrennung über die
Transformatorstrecke aufrechterhält und bis zu 1500~V~DC
isoliert \cite{tea1_datasheet}. Ergänzt wird die Trennung im
Layout durch eine 5~mm breite Trennbahn ohne
Durchkontaktierungen zwischen den beiden Masseflächen. Diese
physikalische Barriere verhindert im Falle von Überspannungen
oder Fehlanschlüssen die Ausbreitung von Störungen zu den
empfindlichen Komponenten der nicht-isolierten Seite. Der
DC/DC-Wandler bildet die einzige Stelle, an der die Barriere
konstruktiv überbrückt wird. Abbildung~\ref{fig:bridge_pcb} zeigt die
Anordnung im Leiterplattenlayout.

\begin{figure}[H]
  \centering
  
  \caption{Leiterplattenlayout der Bridge}
  \label{fig:bridge_pcb}
\end{figure}

Der DMX Ein- und Ausgang ist über
XLR-Einbaubuchsen (NC3MAH bzw. NC3FAH) zugänglich. Für eine mögliche
zukünftige Erweiterung um einen kabelgebundenen
Pixelsteuerungsmodus über Art-Net ist darüber hinaus ein
JST-XH-3-Pin-Ausgang für die WS2815-LED-Datenleitung
vorgesehen. Das Signal wird dabei durch einen
SN75176BP-Transceiver in ein RS-485-Differentialsignal
gewandelt, um eine störungsarme Übertragung über längere
Kabelstrecken zu ermöglichen. Diese Erweiterung ist nicht
Gegenstand der vorliegenden Arbeit.

Tabelle~\ref{tab:pinbelegung-bridge} fasst die Zuordnung der Signale zu
den GPIO-Pins zusammen. Da im Projekt ausschließlich der DMX-Empfang
benötigt wird, teilen sich Sendeleitung und Treiberfreigabe des
RS-485-Transceivers einen Pin, dadurch bleibt ein weiterer GPIO frei.
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

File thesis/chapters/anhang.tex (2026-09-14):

\chapter{Anhang}
\label{chap:anhang}

\section{Schaltpläne}
\label{sec:anhang-schaltplaene}

\begin{figure}[p]
    \centering
    \rotatebox{90}{}
    \caption{Schaltplan der Bridge (Abschnitt~\ref{subsec:bridge-pcb}).}
    \label{fig:sch-bridge}
\end{figure}

\begin{figure}[p]
    \centering
    \rotatebox{90}{}
    \caption{Schaltplan der Leuchtröhre (Abschnitt~\ref{subsec:tube-mainboard}).}
    \label{fig:sch-tube}
\end{figure}

\begin{figure}[p]
    \centering
    \rotatebox{90}{}
    \caption{Schaltplan des Interface-PCB (Abschnitt~\ref{subsec:interface-pcb}).}
    \label{fig:sch-interface}
\end{figure}

\clearpage

\section{Leiterplattenlayouts}
\label{sec:anhang-layouts}
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

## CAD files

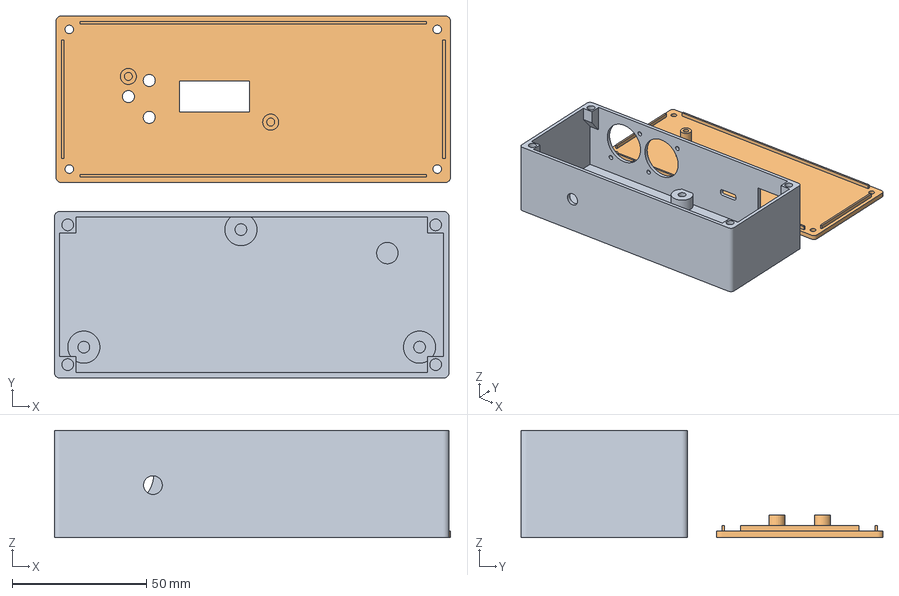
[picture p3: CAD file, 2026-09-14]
body/Bridge.3mf
147.6 x 134.8 x 40.0 mm
Bottom
Top

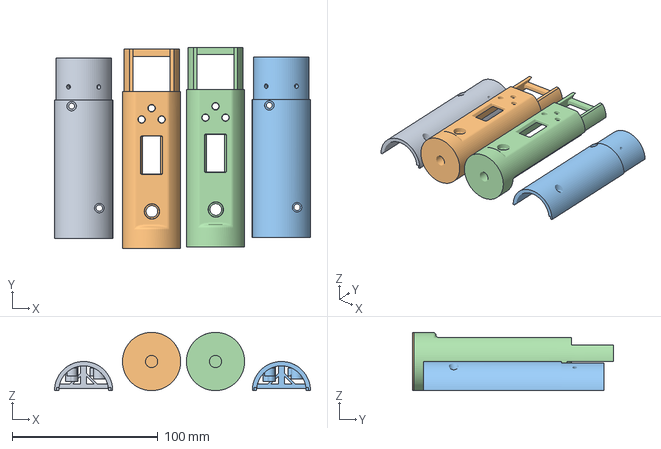
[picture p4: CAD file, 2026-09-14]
body/Tube.3mf
175.8 x 138.3 x 40.0 mm
Back x 2
Front x 2

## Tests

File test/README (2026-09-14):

-Anforderungen an die LED Tube-

V1.0
( )Acrylglas Röhre XT
( )Anschluss entweder in Ablschlusskappe oder an Endstück, dass aufgesetzt wird
( )MPU: ATmega328
( )DMX Steuerung
-> Dip Switch um DMX Adresse einstellen zu können (bis 256)
( )mit dem 9. Schalter kann umgeschalten werden in den Automatik Modus, in dem einfach wahllos Effekte mit 125 BPM angezeigt werden, im automatikmodus über alle kanäle senden
->(konzept der modus wahl nochmal überdenkne)
und dem DMX Modus in dem die Tube angesteuert werden kann.
( )DMX Modi: Farbe auswählen in Wertebereich zwischen 0-255 (Hue) 0-200 => Hue Farbraus/ 201-255 => Farbkombinationen, Helligkeit auf dem zweiten Channel,  und Effektauswahl auf dem 3. 
Effekte: Alles bleibt Dauerhaft an
Langsamer snake von oben nach unten
schnelle snake von oben nach unten (eventuell mehr geschwindigkeitsabstufungen
)
Langsamer snake von unten nach oben
schnelle snake von unten nach oben
strobo
pulsieren schnell
pusieren langsam
doppel pulsieren
RGB Modus in man rot grün und blau einfach an die leds weitergibt(ausgewählt, wenn 9 auf 0 ist sonst normaler modus (effekt, color, brightness)

V2.0
MPU: ESP32
Bluetooth Verbindung 
Steuerung über App
verbauter Akku für ca. 10h Laufzeit
Automatikmodus mit Mikrofon
DMX Adressen bis 512 möglich (größeren Dip Switch wählen oder Funktionstasten hinzufügen)
überlegen, ob Display zur Bedienung sinnvoll ist
Sicherheitsrichtlinien der Elektronik zum Verkauf müsse recherchiert und eingehalten werden

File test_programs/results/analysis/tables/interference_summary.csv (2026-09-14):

Szenario | Verlust [%] | Fenster p95 [%] | Kopien je Seq. | Jitter [ms] | max. Ausfall [ms] | Fenster ab 50 ms [%] | RSSI [dBm]
Nebenzeit | 0.01 | 0.0 | 4.5698333333333325 | 6.4695 | 25 | 0.0 | -83.71733333333333
Stoßzeit | 0.51 | 2.5 | 3.8303666666666665 | 8.453566666666665 | 750 | 0.33333333333333337 | -84.02033333333333

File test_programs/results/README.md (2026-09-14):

# Measurement results & analysis (thesis chapter 7)

Storage and analysis of the evaluation measurement series. **Raw data in `raw/`
is never modified** – every result is reproducibly regenerated in `analysis/`.

```
results/
├── raw/                  # unmodified serial captures (CSV)
└── analysis/
    ├── analyze.py        # generates tables + plots from raw/*.csv
    ├── requirements.txt
    ├── figures/          # *.pdf  -> \includegraphics in the thesis
    └── tables/           # *.tex  -> \input in the thesis  (+ *.csv)
```

No manifest is needed: `analyze.py` processes every CSV in `raw/` and derives the
test type and conditions from the **file name**.

## 1. File-name convention

`<test>_<label>.csv`

| Token | Meaning |
|---|---|
| `test` | first token before the first `_`: `packetloss`, `interference`, `range` or `longterm` |
| `label` | scenario name shown in plots/tables; for `range` it must contain a distance like `5m` or `0.5m` |
| `hidden` | optional token **directly after** `range`: measurement **without line of sight** (`range_hidden_50m.csv`) |

All four test types are recorded with the **same firmware** (`test_reliability_*`).
Only the procedure differs: `interference` adds interferers, `range` is repeated at
several distances, and `longterm` is simply a long capture.

Examples:

```
packetloss_ideal.csv        packetloss_stage.csv
interference_reference.csv  interference_wifi-bt.csv
range_1m.csv  range_5m.csv  range_10m.csv
range_hidden_10m.csv  range_hidden_50m.csv
longterm_4h.csv
```

### Range with and without line of sight

The range test is recorded in two variants: `range_<distance>.csv` with the
receiver in line of sight, `range_hidden_<distance>.csv` with the receiver
**behind a massive obstacle** (building, wall) at the same distance, so the link
only survives via diffraction and reflections. The `hidden` token has to come
directly after `range` – anywhere else it is ignored (with a warning).

Both variants are evaluated **identically**, but as separate series – averaging
one distance curve over two propagation conditions would be meaningless. The
hidden series therefore gets its own outputs with the prefix `range_hidden`:

```
figures/range_distance.pdf          figures/range_hidden_distance.pdf
figures/range_timeseries.pdf        figures/range_hidden_timeseries.pdf
tables/range_summary.tex            tables/range_hidden_summary.tex
tables/range_metrics_full.csv       tables/range_hidden_metrics_full.csv
```

LaTeX labels: `tab:range-summary` and `tab:range-hidden-summary`.

> Encode the measurement conditions in the label (e.g. `interference_3xwifi-2xbt`).
> Note the firmware commit (`git rev-parse --short HEAD`) in your lab notes – it is
> not stored automatically.

## 2. Record a measurement

```bash
# flash the devices
pio run -e test_reliability_bridge -t upload
pio run -e test_reliability_tube   -t upload

# capture the receiver output as raw data (file name = condition)
pio device monitor -e test_reliability_tube | tee results/raw/packetloss_ideal.csv
```

Stop the monitor with `Ctrl-C` after the desired duration (e.g. 60 s; for a
long-term run let it capture for several hours into a `longterm_*.csv`).

## 3. Analyze

```bash
cd results/analysis
pip install -r requirements.txt      # once
python3 analyze.py
```

This produces plots (`figures/*.pdf`) and tables (`tables/*.tex` + `.csv`) per test
type. Include them in the thesis (paths are relative to `thesis/`, where LaTeX runs):

```latex
\input{../test_programs/results/analysis/tables/range_summary.tex}
\includegraphics[width=\linewidth]{../test_programs/results/analysis/figures/range_distance.pdf}
```

The `.tex` tables are German and use `booktabs`. Three details worth knowing:

* Rows recorded **before the first packet arrived** are dropped – the firmware reports
  a fixed 100 % loss for them, which would otherwise become the maximum of every
  window statistic.
* `tables/<test>_metrics_full.csv` contains **every** computed metric, also the ones
  that are not printed in the thesis table (e.g. `win_clean_pct`, `recv_per_seq_min`).
  Any number quoted in the thesis text should be traceable to one of these files.
* Readable scenario names are mapped in `SCENARIO_NAMES` in `analyze.py`; raw file
  names are never changed. Outputs of a test type whose raw data was removed are
  deleted automatically, so `tables/` can never disagree with `raw/`.

## 4. Receiver CSV columns

### Packet loss / interference (`test_packet_loss_tube`, 1 row/s)
| Column | Meaning |
|---|---|
| `t_ms` | receiver timestamp [ms] |
| `win_recv` / `win_exp` / `win_lost` | received / expected / lost in the 1 s window |
| `win_loss_pct` | loss rate in the window [%] |
| `win_max_gap` | longest loss burst in the window (consecutive packets) |
| `cum_*` | same quantities cumulative over the run |
| `cum_max_gap` | longest loss burst overall |
| `iat_mean_ms` | mean inter-arrival time [ms] |
| `jitter_ms` | standard deviation of the inter-arrival time |
| `rssi_avg` / `rssi_min` | signal strength [dBm] (empty if no RSSI samples) |

The **long-term test uses the very same firmware and CSV format** – it is simply a
long packet-loss capture. The analysis then checks whether the performance stays
constant over time (loss trend in %/hour).

> Note: the **burst** (`max_gap`) matters more for flicker assessment than the mean
> loss rate – a single loss holds the last value for only 25 ms (invisible), while a
> long burst becomes visible during motion.

## 5. Which metrics per section

| Thesis section | Primary metrics |
|---|---|
| Packet loss rate | `cum_loss_pct`, `win_loss_pct` (mean/p95), `burst_max_ms` |
| Interference | Δ loss / Δ jitter / Δ `recv_per_seq_mean` (peak vs. off-peak) |
| Range | `cum_loss_pct` and `recv_per_seq_mean` versus distance (per variant, LOS vs. `hidden`) |
| Long-term stability | loss trend over time (%/h ≈ 0 → constant), `loss_pct`, jitter |

> `recv_per_seq_mean` (copies received per sequence value, max. 5) is the metric that
> degrades monotonically with distance, while `cum_loss_pct` does not: the redundant
> transmission absorbs single losses. **Do not** use `rssi_avg` as a path-loss measure –
> the promiscuous sniffer records the last packet seen on the channel, not necessarily
> the payload packet (see thesis section 7.1.4).

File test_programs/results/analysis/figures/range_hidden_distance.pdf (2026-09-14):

Reichweite (ohne Sichtverbindung): Sequenzverlust und Empfangsredundanz über die Distanz

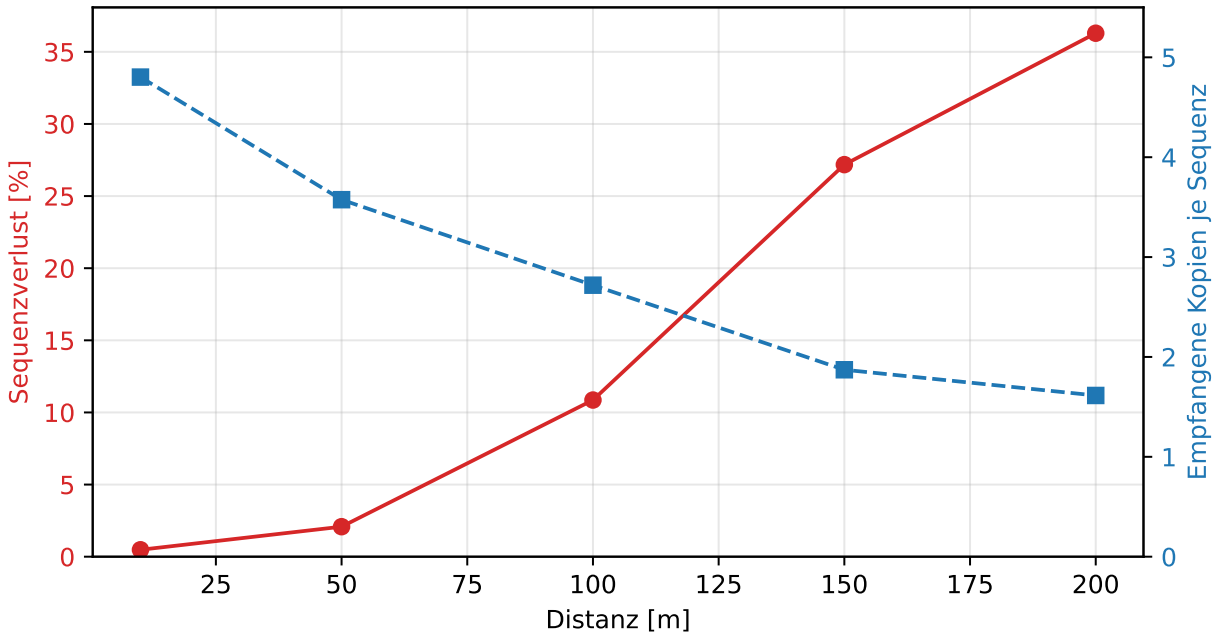
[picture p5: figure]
Distanz [m]; Sequenzverlust [%]; 5 Empfangene Kopien je Sequenz

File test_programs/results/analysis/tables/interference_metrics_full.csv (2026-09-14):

Szenario | duration_s | packets_recv | packets_expected | packets_lost | loss_pct | loss_win_mean_pct | loss_win_p95_pct | loss_win_max_pct | burst_max_steps | burst_max_ms | win_visible_pct | win_clean_pct | jitter_mean_ms | rssi_mean_dbm | rssi_min_dbm | recv_per_seq_mean | recv_per_seq_min
Nebenzeit | 299.0 | 11991 | 11992 | 1 | 0.01 | 0.008333333333333333 | 0.0 | 2.5 | 1 | 25 | 0.0 | 99.66666666666667 | 6.4695 | -83.71733333333333 | -97.0 | 4.5698333333333325 | 4.03
Stoßzeit | 299.0 | 11930 | 11991 | 61 | 0.51 | 0.4506 | 2.5 | 56.6 | 30 | 750 | 0.33333333333333337 | 89.66666666666666 | 8.453566666666665 | -84.02033333333333 | -98.0 | 3.8303666666666665 | 3.0

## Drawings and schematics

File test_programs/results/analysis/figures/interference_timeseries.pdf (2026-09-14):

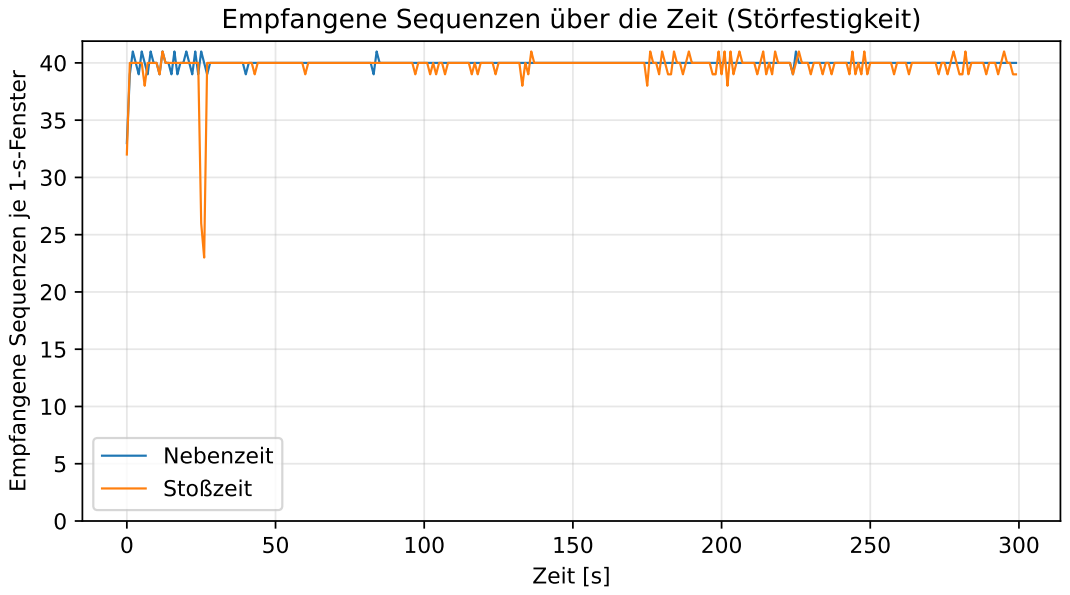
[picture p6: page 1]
Zeit [s]

Empfangene Sequenzen über die Zeit (Störfestigkeit)

Empfangene Sequenzen je 1-s-Fenster

Nebenzeit
Stoßzeit

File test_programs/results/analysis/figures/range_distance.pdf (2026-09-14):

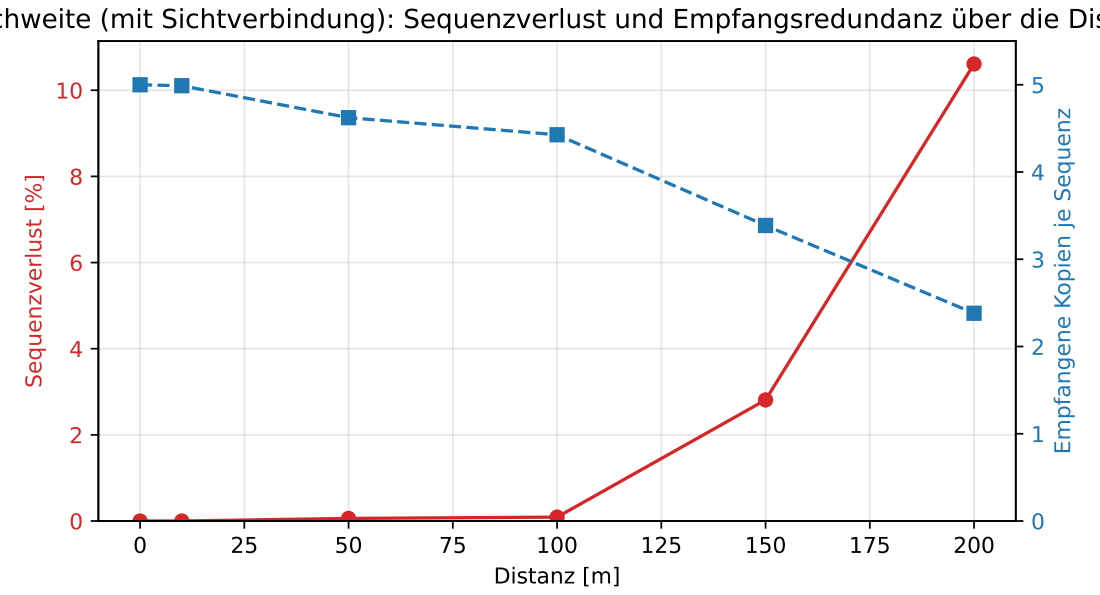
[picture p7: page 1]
Distanz [m]; Sequenzverlust [%]

Reichweite (mit Sichtverbindung): Sequenzverlust und Empfangsredundanz über die Distanz

Empfangene Kopien je Sequenz

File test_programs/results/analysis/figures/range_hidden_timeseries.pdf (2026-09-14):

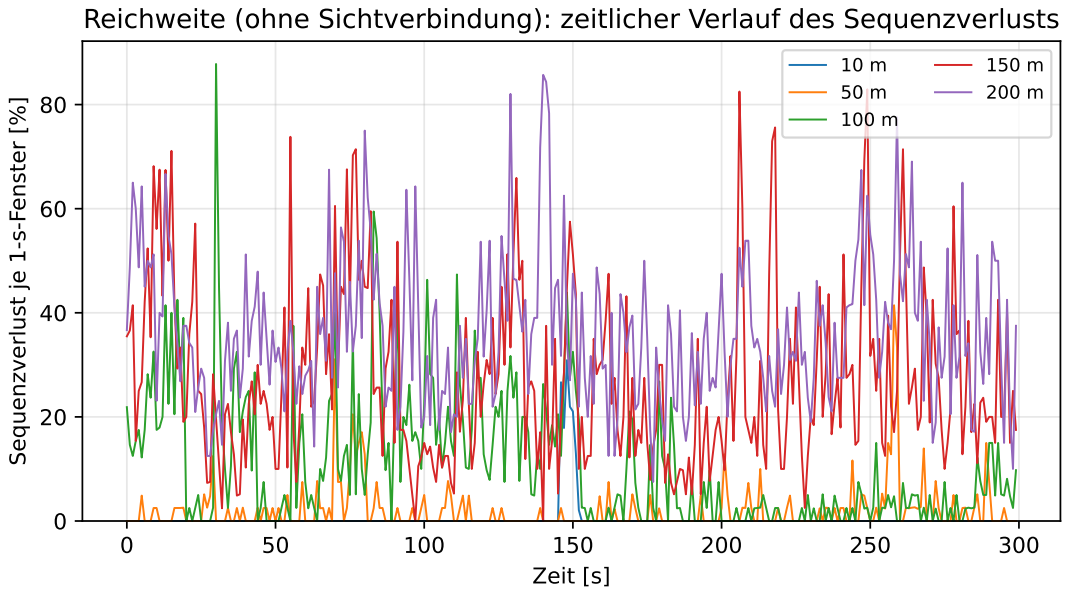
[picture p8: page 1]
Zeit [s]

Reichweite (ohne Sichtverbindung): zeitlicher Verlauf des Sequenzverlusts

Sequenzverlust je 1-s-Fenster [%]

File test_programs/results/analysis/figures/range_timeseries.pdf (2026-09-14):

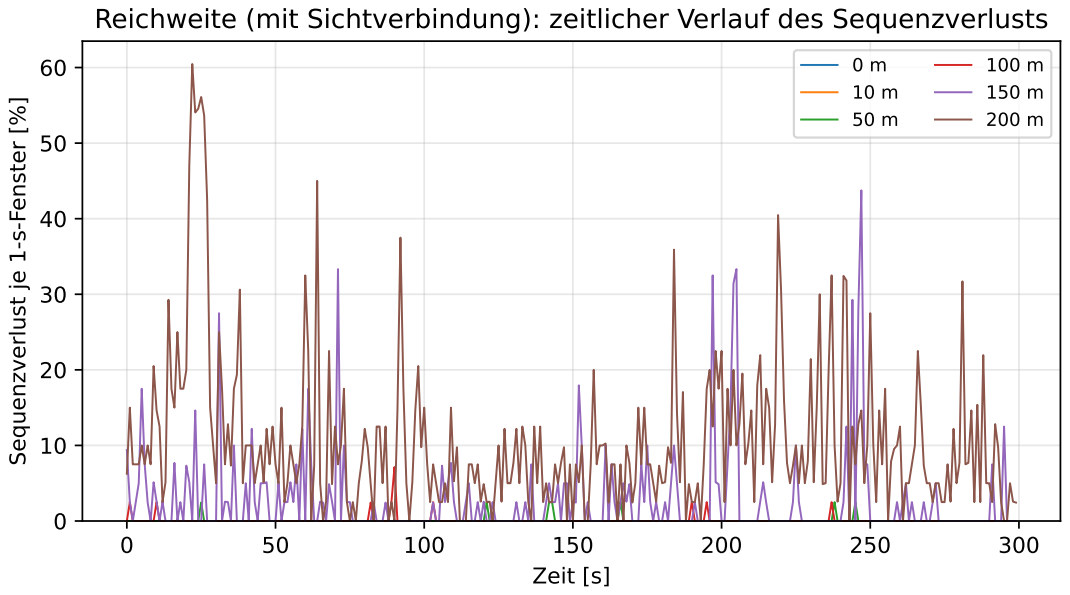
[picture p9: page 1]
Zeit [s]

Reichweite (mit Sichtverbindung): zeitlicher Verlauf des Sequenzverlusts

0 m | 100 m
10 m 50 m | 150 m 200 m

Sequenzverlust je 1-s-Fenster [%]

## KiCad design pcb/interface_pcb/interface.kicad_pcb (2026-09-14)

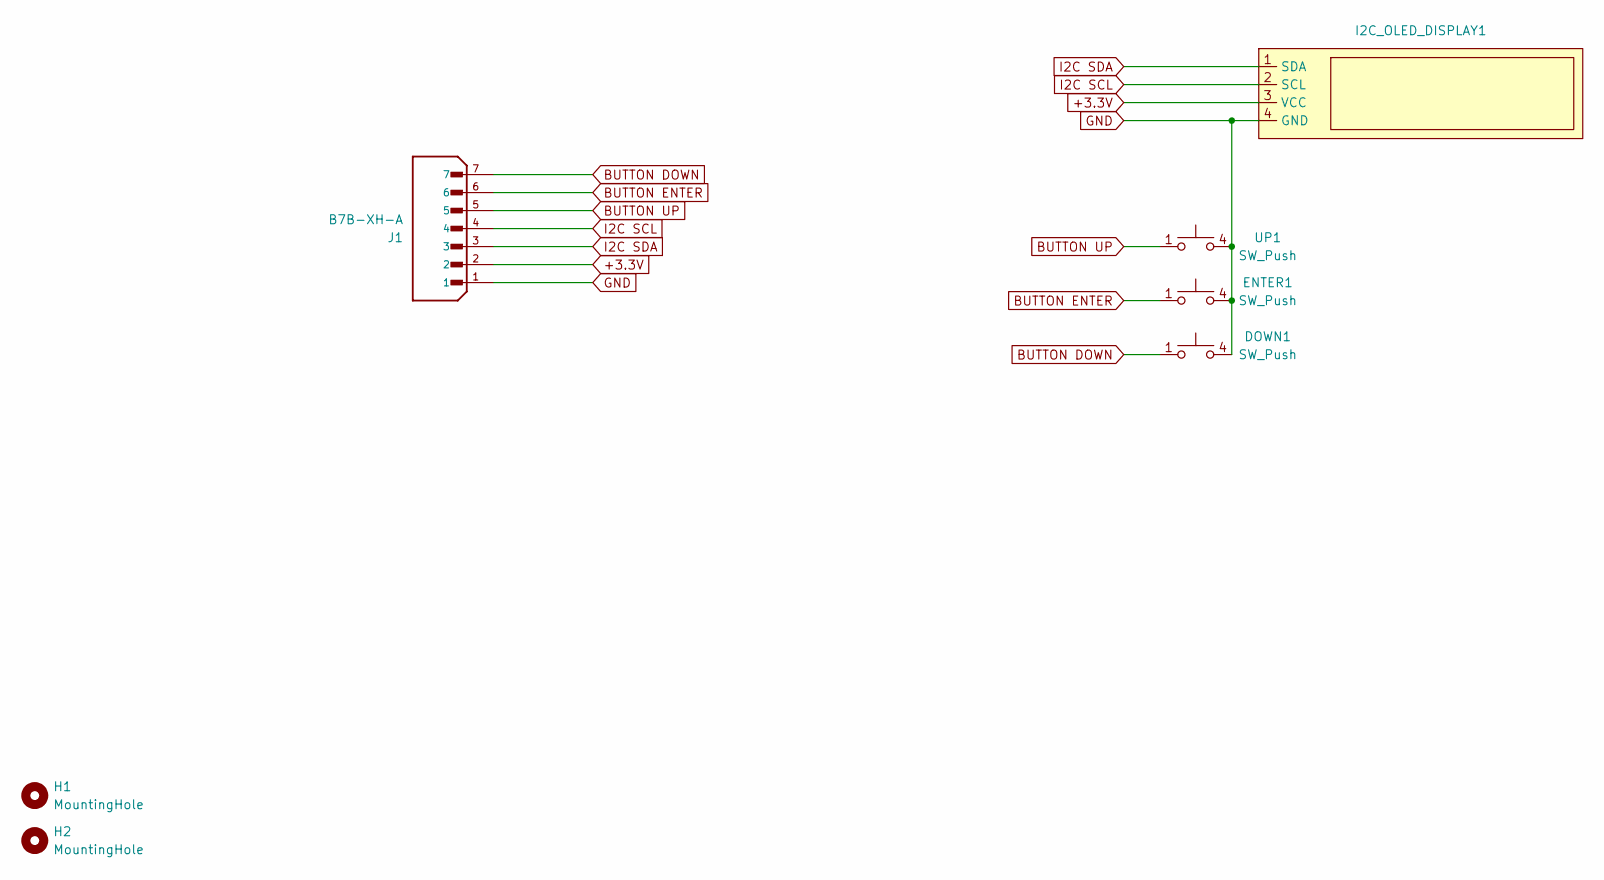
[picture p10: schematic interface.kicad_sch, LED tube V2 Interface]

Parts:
DOWN1: SW_Push; SW_1825910-6-4
ENTER1: SW_Push; SW_1825910-6-4
H1, H2: MountingHole; MountingHole_2.2mm_M2
I2C_OLED_DISPLAY1: MODULE_DM-OLED096-636
J1: B7B-XH-A; JST_B7B-XH-A; PARTREV 7/4/21
UP1: SW_Push; SW_1825910-6-4

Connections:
+3.3V: I2C_OLED_DISPLAY1.3 (VCC), J1.2
BUTTON DOWN: DOWN1.1, J1.7
BUTTON ENTER: ENTER1.1, J1.6
BUTTON UP: J1.5, UP1.1
GND: DOWN1.4, ENTER1.4, I2C_OLED_DISPLAY1.4 (GND), J1.1, UP1.4
I2C SCL: I2C_OLED_DISPLAY1.2 (SCL), J1.4
I2C SDA: I2C_OLED_DISPLAY1.1 (SDA), J1.3

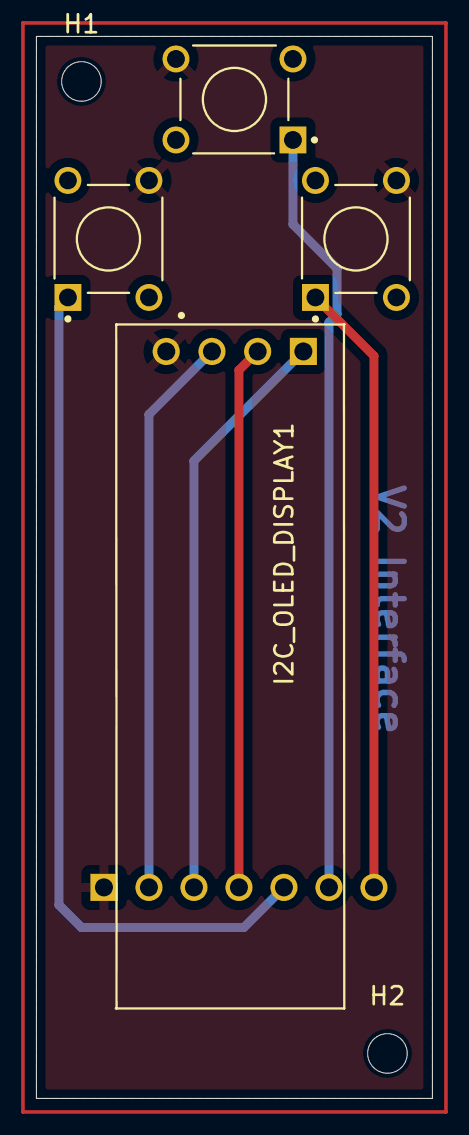
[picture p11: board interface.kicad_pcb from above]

Board: 2 copper layers, 22.0 x 59.0 mm, 7 parts (1 on the bottom side), 7 nets.

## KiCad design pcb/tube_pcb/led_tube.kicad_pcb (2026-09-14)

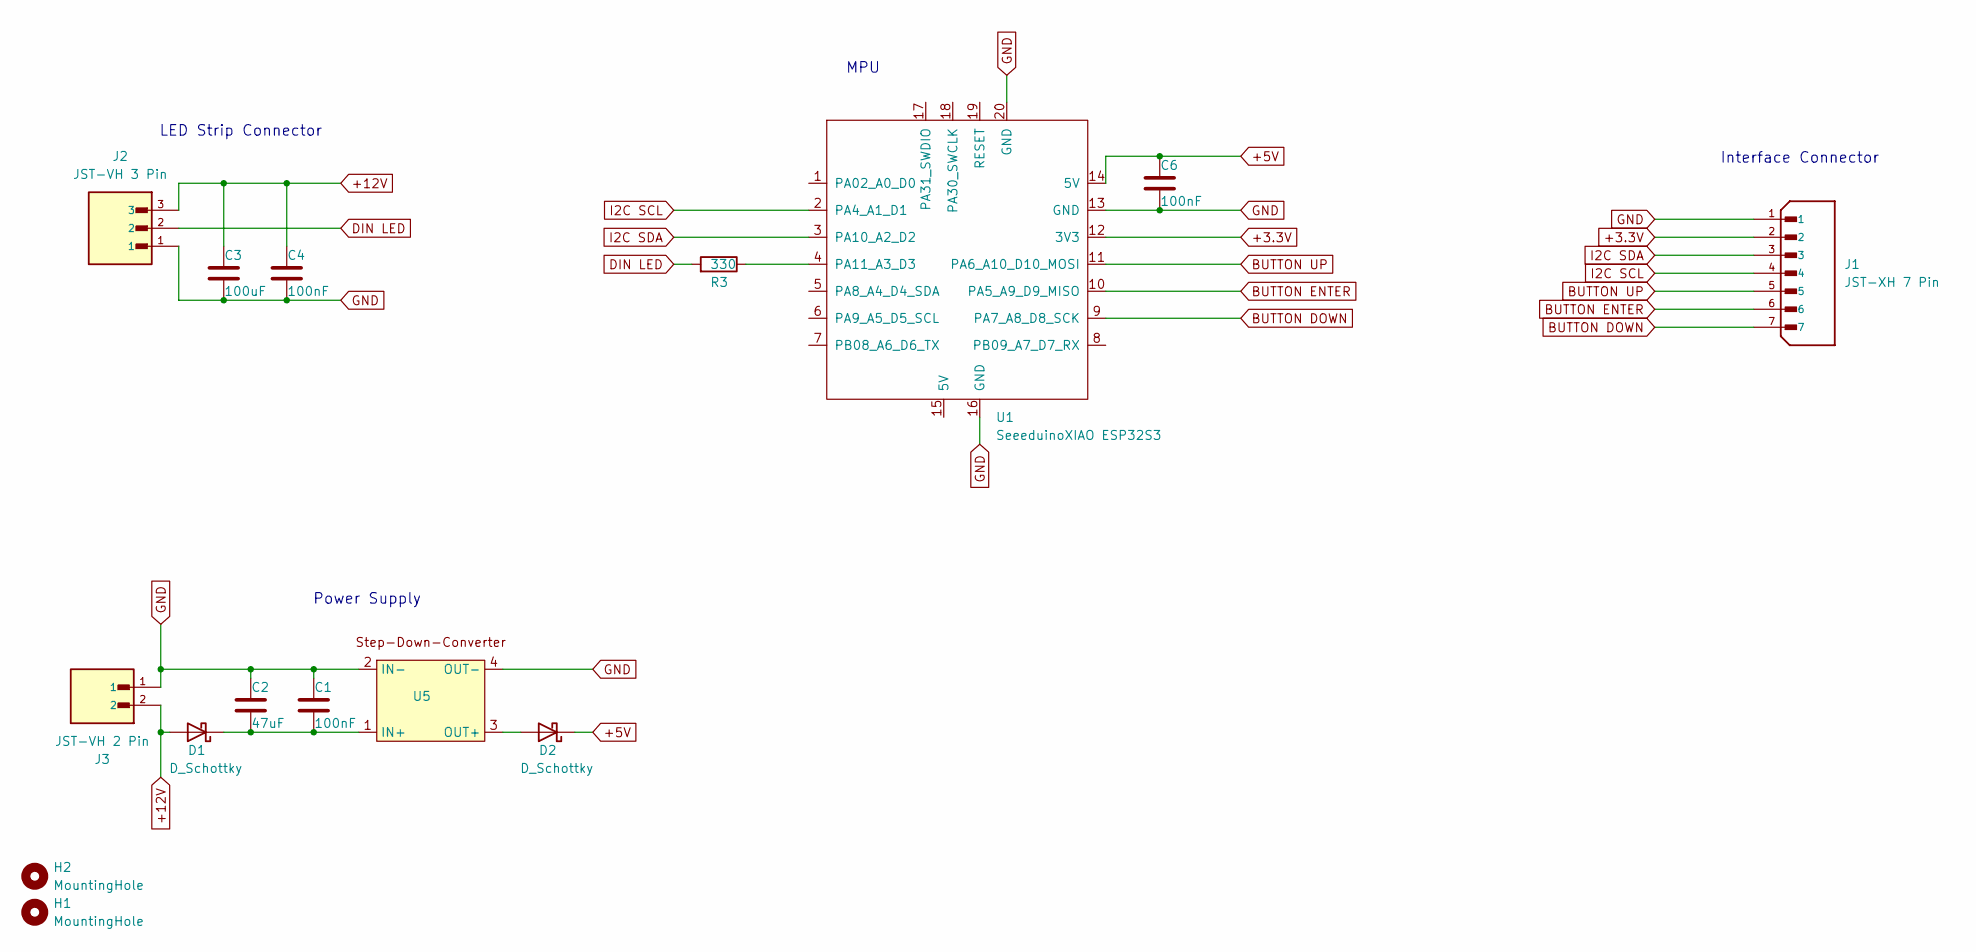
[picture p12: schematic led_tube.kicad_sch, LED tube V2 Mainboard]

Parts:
C1, C4, C6: 100nF; C_1206_3216Metric
C2: 47uF; C_1206_3216Metric
C3: 100uF; C_1206_3216Metric
D1, D2: D_Schottky; D_SMA_Handsoldering
H1, H2: MountingHole; MountingHole_2.2mm_M2
J1: JST-XH 7 Pin; JST_B7B-XH-A; PARTREV 7/4/21
J2: JST-VH 3 Pin; JST_B3P-VH_LF__SN_; PARTREV NA
J3: JST-VH 2 Pin; JST_B2P-VH_LF__SN_; PARTREV NA
R3: 330; R_1206_3216Metric
U1: SeeeduinoXIAO ESP32S3; Seeeduino XIAO-MOUDLE14P-2.54-21X17.8MM
U5: Step-Down-Converter DCDC

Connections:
+3.3V: J1.2, U1.12 (3V3)
+5V: C6.1, D2.1 (K), U1.14 (5V)
+12V: C3.1, C4.1, D1.2 (A), J2.3, J3.2
BUTTON DOWN: J1.7, U1.9 (PA7_A8_D8_SCK)
BUTTON ENTER: J1.6, U1.10 (PA5_A9_D9_MISO)
BUTTON UP: J1.5, U1.11 (PA6_A10_D10_MOSI)
DIN LED: J2.2, R3.2
GND: C1.1, C2.1, C3.2, C4.2, C6.2, J1.1, J2.1, J3.1, U1.13 (GND), U1.16 (GND), U1.20 (GND), U5.2 (IN-), U5.4 (OUT-)
I2C SCL: J1.4, U1.2 (PA4_A1_D1)
I2C SDA: J1.3, U1.3 (PA10_A2_D2)
unnamed: C1.2, C2.2, D1.1 (K), U5.1 (IN+)
unnamed: D2.2 (A), U5.3 (OUT+)
unnamed: R3.1, U1.4 (PA11_A3_D3)

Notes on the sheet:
Power Supply
LED Strip Connector
Interface Connector
MPU

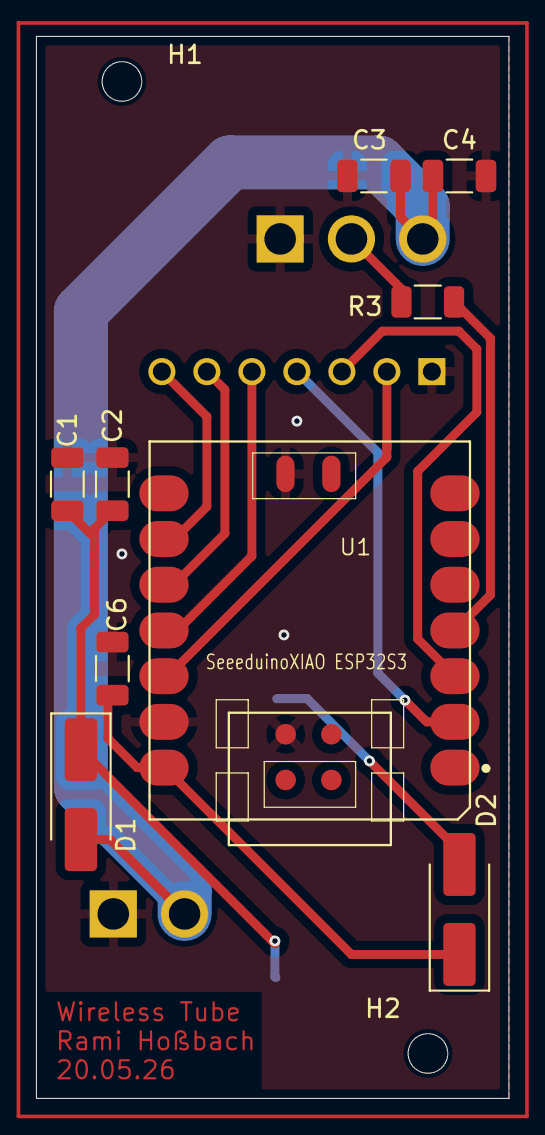
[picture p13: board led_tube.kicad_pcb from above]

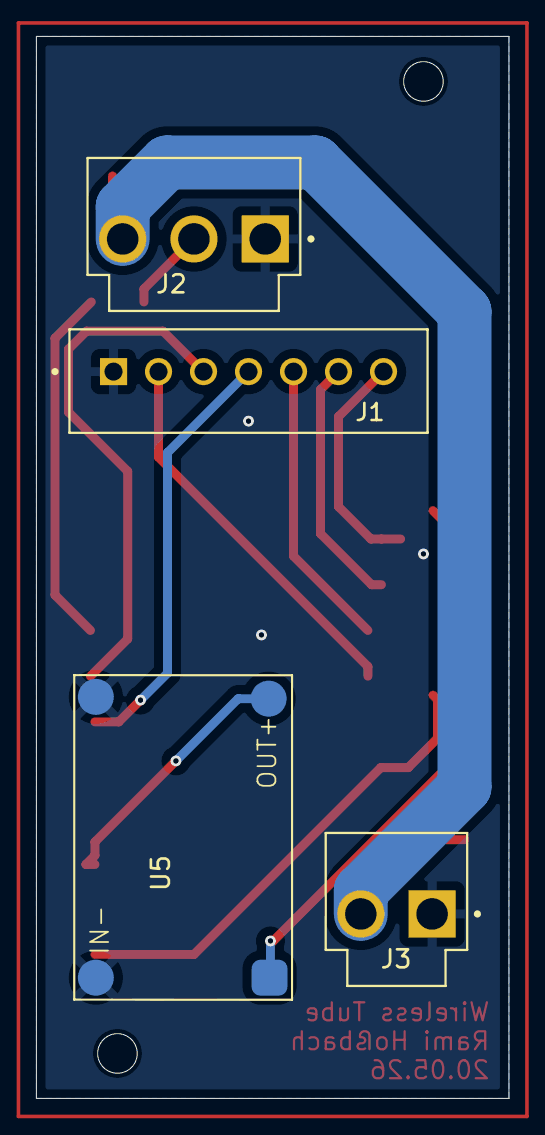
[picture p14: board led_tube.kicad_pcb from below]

Board: 2 copper layers, 26.2 x 59.0 mm, 15 parts (4 on the bottom side), 13 nets.

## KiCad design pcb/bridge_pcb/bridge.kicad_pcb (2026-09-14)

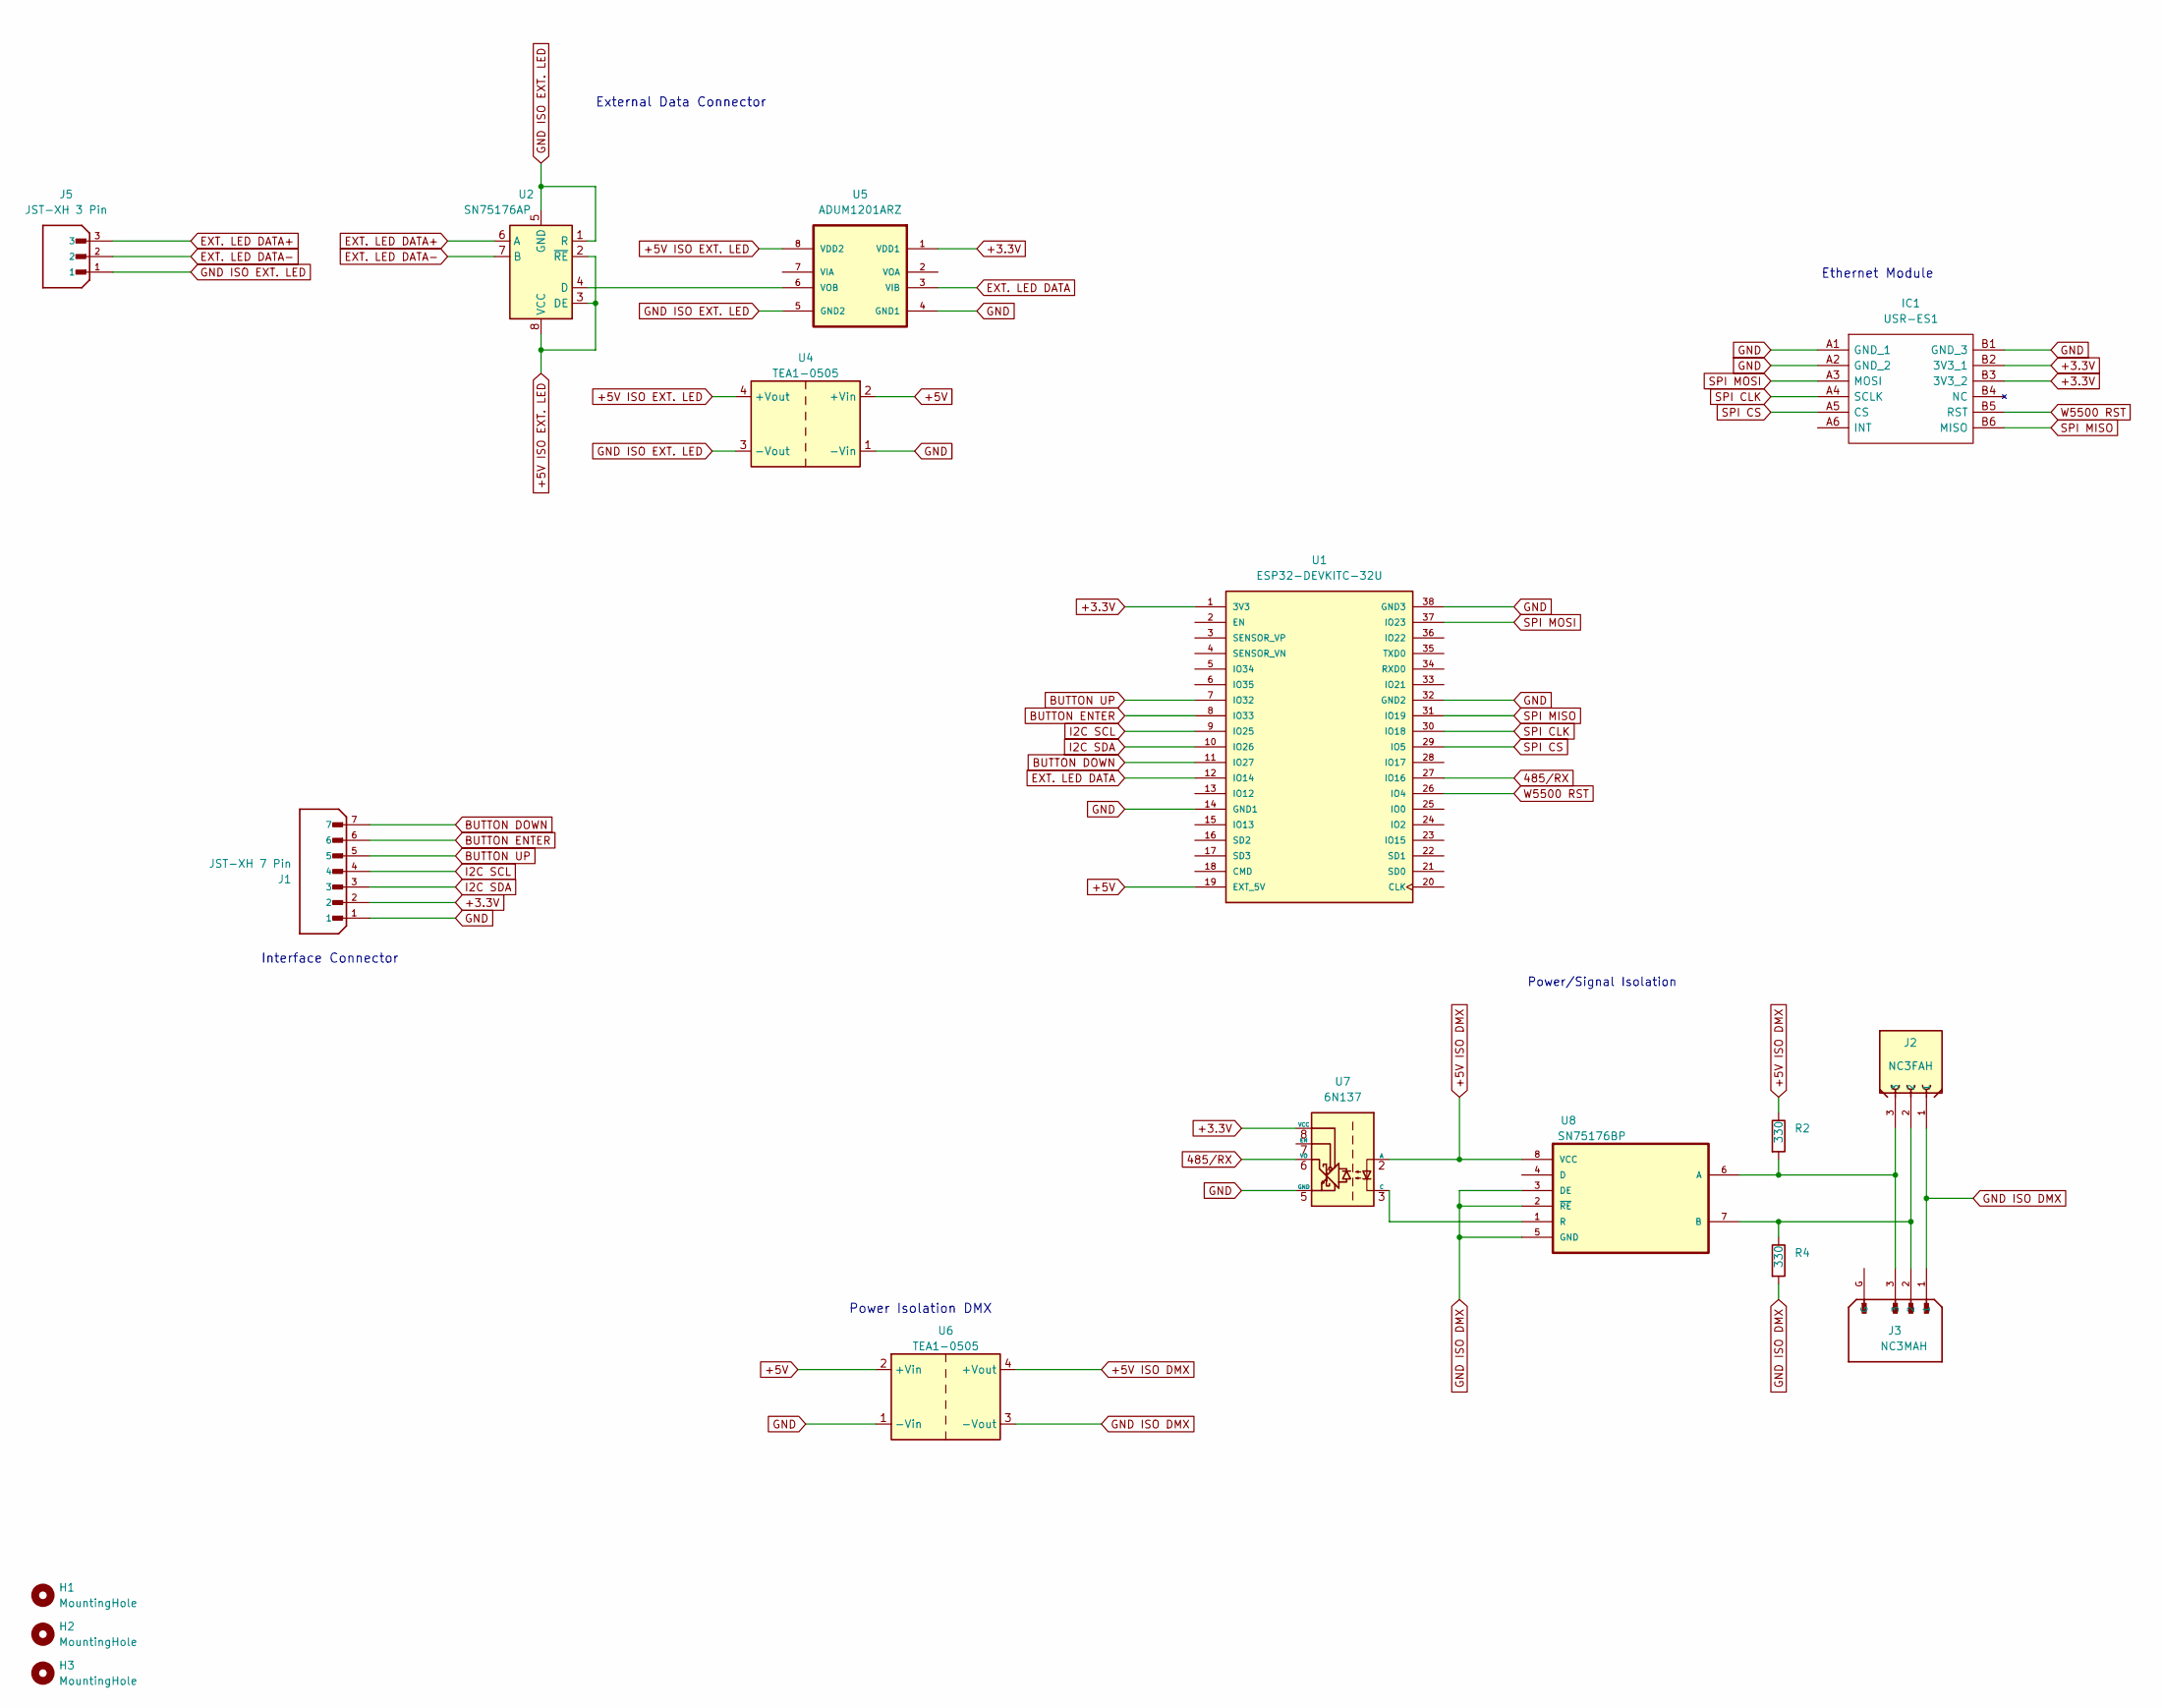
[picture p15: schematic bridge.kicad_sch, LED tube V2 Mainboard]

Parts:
H1, H2, H3: MountingHole; MountingHole_3.2mm_M3
IC1: USR-ES1; USRES1; Manufacturer_Part_Number USR-ES1
J1: JST-XH 7 Pin; JST_B7B-XH-A; PARTREV 7/4/21
J2: NC3FAH; NEUTRIK_NC3FAH; PARTREV 07.03.19
J3: NC3MAH; NEUTRIK_NC3MAH; PARTREV 30.03.09
J5: JST-XH 3 Pin; JST_XH-A_LF__SN_3-Pin; PARTREV 7/4/21
R2, R4: 330; R_1206_3216Metric
U1: ESP32-DEVKITC-32U; MODULE_ESP32-DEVKITC-32U; PARTREV V4
U2: SN75176AP; DIP-8_W7.62mm
U4, U6: TEA1-0505; Converter_DCDC_TRACO_TEA1-xxxx_THT
U5: ADUM1201ARZ; MPN ADUM1201ARZ
U7: 6N137; DIP-8_W7.62mm
U8: SN75176BP; DIP794W45P254L959H508Q8

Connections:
485/RX: U1.27 (IO16), U7.6 (VO)
+3.3V: IC1.B2 (3V3_1), IC1.B3 (3V3_2), J1.2, U1.1 (3V3), U5.1 (VDD1), U7.8 (VCC)
+5V: U1.19 (EXT_5V), U4.2 (+Vin), U6.2 (+Vin)
+5V ISO DMX: R2.1, U6.4 (+Vout), U7.2 (A), U8.8 (VCC)
+5V ISO EXT. LED: U2.2 (~RE), U2.3 (DE), U2.8 (VCC), U4.4 (+Vout), U5.8 (VDD2)
BUTTON DOWN: J1.7, U1.11 (IO27)
BUTTON ENTER: J1.6, U1.8 (IO33)
BUTTON UP: J1.5, U1.7 (IO32)
EXT. LED DATA: U1.12 (IO14), U5.3 (VIB)
EXT. LED DATA+: J5.3, U2.6 (A)
EXT. LED DATA-: J5.2, U2.7 (B)
GND: IC1.A1 (GND_1), IC1.A2 (GND_2), IC1.B1 (GND_3), J1.1, U1.14 (GND1), U1.32 (GND2), U1.38 (GND3), U4.1 (-Vin), U5.4 (GND1), U6.1 (-Vin), U7.5 (GND)
GND ISO DMX: J2.1, J3.1, R4.2, U6.3 (-Vout), U8.2 (~RE), U8.3 (DE), U8.5 (GND)
GND ISO EXT. LED: J5.1, U2.1 (R), U2.5 (GND), U4.3 (-Vout), U5.5 (GND2)
I2C SCL: J1.4, U1.9 (IO25)
I2C SDA: J1.3, U1.10 (IO26)
unnamed: U2.4 (D), U5.6 (VOB)
unnamed: U7.3 (C), U8.1 (R)
unnamed: J2.3, J3.3, R2.2, U8.6 (A)
unnamed: J2.2, J3.2, R4.1, U8.7 (B)
SPI CLK: IC1.A4 (SCLK), U1.30 (IO18)
SPI CS: IC1.A5 (CS), U1.29 (IO5)
SPI MISO: IC1.B6 (MISO), U1.31 (IO19)
SPI MOSI: IC1.A3 (MOSI), U1.37 (IO23)
W5500 RST: IC1.B5 (RST), U1.26 (IO4)

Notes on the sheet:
External Data Connector
Power/Signal Isolation
Power Isolation DMX
Interface Connector
Ethernet Module

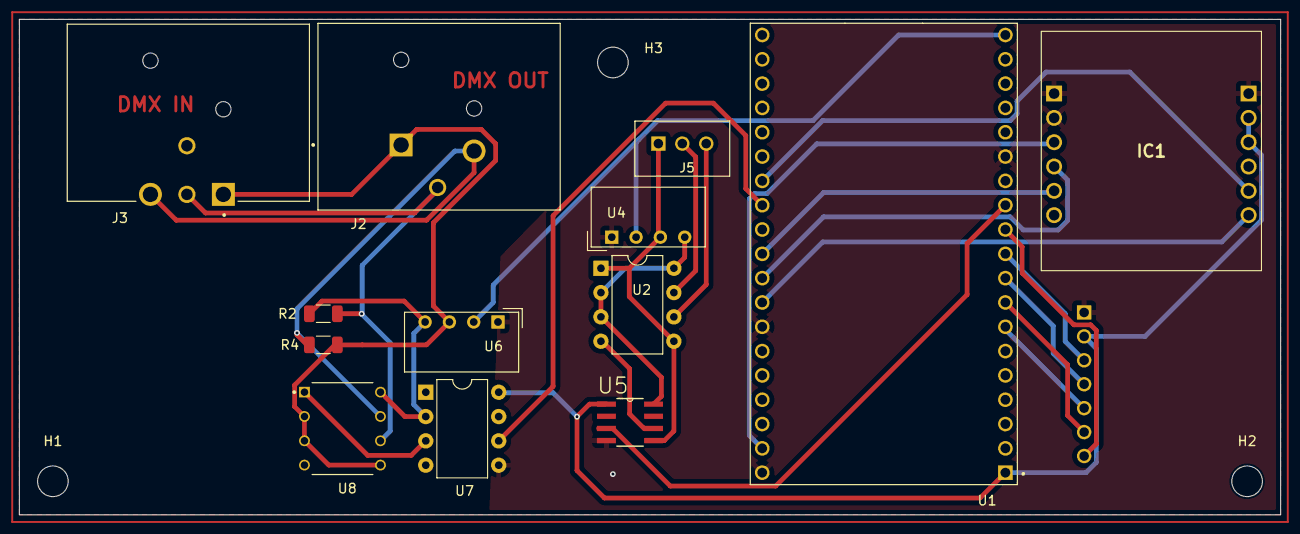
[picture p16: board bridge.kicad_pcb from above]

Board: 2 copper layers, 131.8 x 51.8 mm, 17 parts (1 on the bottom side), 25 nets.

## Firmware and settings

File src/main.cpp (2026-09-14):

#include <Arduino.h>
#include <FastLED.h>
#include <Wire.h>
#include <Adafruit_GFX.h>
#include <Adafruit_SSD1306.h>
#include "LedController.hpp"
#include "WirelessDmx.hpp"
#include "TubeController.hpp"
#include "Menu.hpp"
#include "Display.hpp"
#include "DmxReceiver.hpp"
#include "ArtNetReceiver.hpp"
#include "Config.hpp"


Adafruit_SSD1306 display(SCREEN_WIDTH, SCREEN_HEIGHT, &Wire, OLED_RESET);
Menu menu;
WirelessDmxController wireless_dmx;
LedController led_controller;

#if DEVICE_MODE == DEVICE_MODE_BRIDGE

DmxReceiver dmx;
TubeController tube_controller;
ArtNetReceiver artnet;

void artnet_task(void *pvParameters) {
    for (;;) {
        artnet.parse();
        vTaskDelay(2); 
    }
}
#endif

void setup() {
    Serial.begin(115200);
    menu.begin();
    led_controller.begin();
    wireless_dmx.init(menu.get_channel());

#if DEVICE_MODE == DEVICE_MODE_BRIDGE
    dmx.begin();

    Serial.println("Starting ArtNet Controller...");
    artnet.begin();
    artnet.set_universe(0, 0, 0);

    xTaskCreatePinnedToCore(
        artnet_task,             /*task function*/
        "ArtNetTask",            /*name of task*/
        10000,                   /*stack size of task*/
        NULL,                    /*parameter of the task*/
        tskIDLE_PRIORITY,                       /*priority of the task*/
        NULL,                    /*task handle to keep track of the created task*/
        0);                      /*core number to run the task*/
#endif
}

void loop() {
    menu.handle();
    wireless_dmx.sync_channel(menu.get_channel());

#if DEVICE_MODE == DEVICE_MODE_TUBE

    switch(menu.get_mode()) {
        case 0: { /* Standalone Mode */
            CRGB c = menu.get_color();
            led_controller.set_input(TubeInput{menu.get_effect(), c.r, c.g, c.b});
            break;
        }

        case 1: /* Wireless DMX Mode */
            led_controller.set_input(wireless_dmx.read(menu.get_address()));
            break;
            
        default:
            Serial.println("Error: Invalid Mode Selected");
    }

    led_controller.handle();

#elif DEVICE_MODE == DEVICE_MODE_BRIDGE

    switch(menu.get_mode()) {
        case 0: /* Master Bridge Mode */
            tube_controller.set_tubes_size(menu.get_tube_number());
            tube_controller.set_bpm(menu.get_bpm());
            menu.is_color_auto()  ? tube_controller.cycle_color()  : tube_controller.set_color(menu.get_color());
            menu.is_effect_auto() ? tube_controller.cycle_effect() : tube_controller.set_effect(menu.get_effect());
            tube_controller.set_tube_effect(menu.get_tube_effect());

            tube_controller.handle();
            wireless_dmx.write(tube_controller.get_payload());
            break;

        case 1: /* Wireless DMX Bridge Mode */
            dmx.update();
            wireless_dmx.write(dmx.read(menu.get_address(), menu.get_tube_number()));
            break;

        case 2: /* ArtNet Bridge Mode */
            artnet.check_and_reinit();
            if (artnet.new_packet()) {
                wireless_dmx.write(artnet.read_frame(menu.get_address(), menu.get_tube_number()));
            }
            break;

        // Replaced by the ArtNet Bridge Mode above. Kept for a possible rollback:
        // case 2: /* Pixel Controller Bridge Mode */
        //     artnet.check_and_reinit();
        //     if(artnet.new_packet()) {
        //         led_controller.set_input(artnet.read());
        //         led_controller.handle();
        //     }
        //     break;

        default:
            Serial.println("Error: Invalid Mode Selected");
    }

#endif

    //printCycleCount();
}

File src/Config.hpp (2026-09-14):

#ifndef PROJECT_CONFIG_H
#define PROJECT_CONFIG_H

#include <Arduino.h>

#define DEVICE_MODE_TUBE 0
#define DEVICE_MODE_BRIDGE 1

/* Pin configuration */

#if DEVICE_MODE == DEVICE_MODE_TUBE
//LEDs
constexpr uint8_t LED_DATA_PIN = 4;

//I2C Display
constexpr uint8_t I2C_SCL = 2;
constexpr uint8_t I2C_SDA = 3;

//Menu Buttons
constexpr uint8_t PIN_UP = 7;
constexpr uint8_t PIN_DOWN = 9;
constexpr uint8_t PIN_ENTER = 8;


// /* pins for deprecated tube pcb v1 */
// constexpr uint8_t LED_DATA_PIN = 21;
// // constexpr uint8_t ENABLE_INTERNAL_LED_CONTROL_PIN = 5; //TODO: change to correct pins
// // constexpr uint8_t ENABLE_EXTERNAL_LED_CONTROL_PIN = 6;

// //I2C Display
// constexpr uint8_t I2C_SCL = 26;
// constexpr uint8_t I2C_SDA = 25;

// //Menu Buttons
// constexpr uint8_t PIN_UP = 33;
// constexpr uint8_t PIN_DOWN = 32;
// constexpr uint8_t PIN_ENTER = 27;

#elif DEVICE_MODE == DEVICE_MODE_BRIDGE
//LEDs
constexpr uint8_t LED_DATA_PIN = 14;

//I2C Display
constexpr uint8_t I2C_SCL = 25;
constexpr uint8_t I2C_SDA = 26;

//Menu Buttons
constexpr uint8_t PIN_UP = 27;
constexpr uint8_t PIN_DOWN = 32;
constexpr uint8_t PIN_ENTER = 33;

//Ethernet Module USR ES1 (W5500)
constexpr uint8_t W5500_RST = 4;
constexpr uint8_t SPI_CS = 5;                         
constexpr uint8_t SPI_SCK  = 18;
constexpr uint8_t SPI_MISO = 19;
constexpr uint8_t SPI_MOSI = 23;

//DMX
constexpr uint8_t RX_DMX = 16;
constexpr uint8_t TX_DMX = 17; //unneeded
constexpr uint8_t EN_DMX = 17; // Only RX is needed in project, so set EN to TX to save free pins

#endif

//I2C Display


// LED configuration
constexpr uint8_t NUM_LEDS = 120;

constexpr uint8_t OVERHEAD_DMX_FRAME = 2; // size + start_address bytes
constexpr uint8_t MAX_WDMX_CHANNELS = 240; //esp-now v1 is restricted to 250 byte
constexpr uint8_t MAX_WDMX_FRAME_SIZE = MAX_WDMX_CHANNELS + OVERHEAD_DMX_FRAME;

constexpr uint8_t TUBE_DATASET_SIZE = 4;

//delete this function after development is done
// void printCycleCount() {
//     static unsigned long lastMillis = 0;
//     static unsigned long cycleCount = 0;
//     cycleCount++;
//     unsigned long now = millis();
//     if(now - lastMillis >= 1000) {
//         Serial.print("Cycles pro Sekunde: ");
//         Serial.println(cycleCount);
//         cycleCount = 0;
//         lastMillis = now;
//     }
// }

#endif

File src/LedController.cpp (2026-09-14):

#include "LedController.hpp"

/* ================= TIMING ================= */
static constexpr uint8_t TARGET_FPS        = 60;
static constexpr uint8_t FRAME_INTERVAL_MS = 1000 / TARGET_FPS; // 16 ms

static constexpr uint16_t SWEEP_PERIOD_MS = 2000; // block travels the strip once
static constexpr uint8_t  SWEEP_LENGTH    = 20;   // LEDs lit by the sweeping block

/** @brief Registers the strip with FastLED. Call from setup(). */
void LedController::begin() {
    FastLED.addLeds<WS2812B, LED_DATA_PIN, RGB>(leds, NUM_LEDS); // WS2412
    //FastLED.addLeds<WS2812B, LED_DATA_PIN, GRB>(leds, NUM_LEDS); // WS2814

    Serial.println("LED Controller initialized");
}

/**
 * @brief Switches to a new effect and restarts its animation phase.
 *
 * Resetting the time base is what makes an effect start at its beginning. Strip
 * and heat buffer are cleared too, so fire() and sparkle() -- the only effects
 * building on the previous frame -- do not inherit the picture before them.
 *
 * @param new_effect The effect ID to switch to.
 */
void LedController::set_effect(uint8_t new_effect) {
    if (new_effect == effect) return;

    effect = new_effect;
    effect_start_ms = millis();

    memset(heat, 0, sizeof(heat));
    fill_solid(leds, NUM_LEDS, CRGB::Black);
}

void LedController::set_input(CRGB input_color) {
    set_effect(LED_SOLID);
    color.r = input_color.r;
    color.g = input_color.g;
    color.b = input_color.b;
}

/**
 * @brief Sets the controller's state from a received tube dataset.
 *
 * @param input A TubeInput struct. Including effect, red, green, and blue values.
 */
void LedController::set_input(TubeInput input) {
    set_effect(input.effect);
    color.r = input.red;
    color.g = input.green;
    color.b = input.blue;
}

/**
 * @brief Sets LED pixel data directly from external input.
 *
 * This method copies pixel data from the input buffer to the internal LED array.
 * It is currently only used by the bridge device in artnet mode.
 *
 * @param input PixelControlInput struct containing pixel data and size
 * @note Currently only used by the bridge device
 */
void LedController::set_input(PixelControlInput input) {
    uint16_t bytes_to_copy = sizeof(CRGB) * min(input.size, (uint16_t)NUM_LEDS);
    memcpy(leds, input.pixels, bytes_to_copy);
}


uint8_t LedController::exponential_increase(uint8_t x){
    float normalized_x = x / 255.0f;
    float squared = normalized_x * normalized_x;
    float y = squared * squared * 255.0f;
    return static_cast<uint8_t>(y);
}

void LedController::fill_solid(struct CRGB * target_array, int num_to_fill, const struct CRGB& color) {
     for( int i = 0; i < num_to_fill; ++i) {
        target_array[i] = color;
    }
}

/* ================= DRAWING PRIMITIVES ================= */

void LedController::clear() {
    fill_solid(leds, NUM_LEDS, CRGB::Black);
}

/** @brief The selected color, scaled to @p brightness. */
CRGB LedController::scaled_color(uint8_t brightness) {
    return CRGB(color.r * brightness / 255, color.g * brightness / 255, color.b * brightness / 255);
}

/**
 * @brief Position of the sweeping block for a given phase.
 *
 * @param phase     Elapsed time within the current sweep, in [0, period_ms).
 * @param period_ms Duration of one full travel across the strip.
 * @return Index of the block's lower end, running from -SWEEP_LENGTH to NUM_LEDS.
 */
int16_t LedController::sweep_position(uint32_t phase, uint16_t period_ms) {
    const uint16_t travel = NUM_LEDS + SWEEP_LENGTH;
    return static_cast<int16_t>((phase * travel) / period_ms) - SWEEP_LENGTH;
}

/**
 * @brief Fills a block of SWEEP_LENGTH LEDs starting at @p position.
 *
 * The block is clipped to the strip, so positions that reach partly or fully
 * outside it are safe.
 *
 * @param position Index of the block's lower end. May be negative.
 */
void LedController::draw_block(int16_t position) {
    int16_t start = position < 0 ? 0 : position;
    int16_t end   = position + SWEEP_LENGTH;
    if (end > NUM_LEDS) end = NUM_LEDS;

    if (end > start) fill_solid(&leds[start], end - start, color);
}

/**
 * @brief Draws a moving head with a tail fading out behind it.
 *
 * The tail is computed from the head position alone rather than by dimming the
 * previous frame, which keeps the effects that use it pure functions of the
 * elapsed time. Pixels outside the strip are skipped, so a head that has already
 * left the tube still drags its tail out correctly.
 *
 * @param head      Index of the brightest pixel. May lie outside the strip.
 * @param length    Distance from the head to the dark end of the tail, in LEDs.
 * @param direction Direction of travel: +1 towards the top, -1 towards the bottom.
 *                  The tail trails against it.
 */
void LedController::draw_tail(int16_t head, uint8_t length, int8_t direction) {
    for (uint8_t distance = 0; distance < length; ++distance) {
        int16_t index = head - direction * static_cast<int16_t>(distance);
        if (index < 0 || index >= NUM_LEDS) continue;

        uint8_t ramp = 255 - static_cast<uint8_t>(distance * 255 / length);
        leds[index] = scaled_color(exponential_increase(ramp));
    }
}

/**
 * @brief Builds the ramp fire() maps its heat through.
 *
 * Runs black -> dimmed color -> color -> washed out towards white, so the RGB
 * channels still choose the character of the flame instead of being ignored the
 * way a fixed heat palette would.
 */
CRGBPalette16 LedController::fire_palette() {
    CRGB dim  = scaled_color(70);
    CRGB hot  = color;
    CRGB peak = CRGB(qadd8(color.r, 160), qadd8(color.g, 160), qadd8(color.b, 160));

    return CRGBPalette16(CRGB::Black, dim, hot, peak);
}

/* ================= EFFECTS ================= */

void LedController::solid_color_mode() {
    fill_solid(leds, NUM_LEDS, color);
}

/**
 * @brief Smoothly pulses all LEDs up and down in brightness.
 *
 * The brightness follows a triangle across @p period_ms, shaped by
 * exponential_increase() so the ramp is perceived as even.
 *
 * @param elapsed   Time since the effect was selected, in ms.
 * @param period_ms Duration of one full up+down cycle.
 */
void LedController::pulse(uint32_t elapsed, uint16_t period_ms) {
    uint32_t phase = elapsed % period_ms;
    uint32_t half  = period_ms / 2;

    uint8_t ramp = (phase < half)
        ? static_cast<uint8_t>(phase * 255 / half)
        : static_cast<uint8_t>((period_ms - phase) * 255 / (period_ms - half));

    fill_solid(leds, NUM_LEDS, scaled_color(exponential_increase(ramp)));
}

void LedController::bottom_to_top(uint32_t elapsed) {
    clear();
    draw_block(sweep_position(elapsed % SWEEP_PERIOD_MS, SWEEP_PERIOD_MS));
}

void LedController::top_to_bottom(uint32_t elapsed) {
    clear();

    int16_t position = sweep_position(elapsed % SWEEP_PERIOD_MS, SWEEP_PERIOD_MS);
    draw_block(NUM_LEDS - SWEEP_LENGTH - position); // mirrored along the strip
}
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

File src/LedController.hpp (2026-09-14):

#ifndef LED_CONTROLLER_H
#define LED_CONTROLLER_H

#include <Arduino.h>
#include <FastLED.h>
#include "Dto.hpp"
#include "Config.hpp"

enum LedEffect : uint8_t {
    LED_SOLID              = 0,
    LED_PULSE              = 1,
    LED_PULSE_SLOW         = 2,
    LED_PULSE_FAST         = 3,
    LED_BOTTOM_TO_TOP      = 4,
    LED_TOP_TO_BOTTOM      = 5,
    LED_UP_AND_DOWN        = 6,
    LED_STROBO             = 10,

    LED_RAINBOW            = 100, 
    LED_RAINBOW_FLOW_SLOW  = 101,
    LED_RAINBOW_FLOW       = 102,
    LED_RAINBOW_FLOW_FAST  = 103,

    LED_COMET_SLOW         = 110,
    LED_COMET              = 111,
    LED_COMET_FAST         = 112,

    LED_SCANNER_SLOW       = 120,
    LED_SCANNER            = 121,
    LED_SCANNER_FAST       = 122,

    LED_CENTER_OUT_SLOW    = 130,
    LED_CENTER_OUT         = 131,
    LED_CENTER_OUT_FAST    = 132,

    LED_FIRE_CALM          = 140,
    LED_FIRE               = 141,
    LED_FIRE_WILD          = 142,

    LED_PLASMA_SLOW        = 150,
    LED_PLASMA             = 151,
    LED_PLASMA_FAST        = 152,

    LED_BOUNCE_SLOW        = 160,
    LED_BOUNCE             = 161,
    LED_BOUNCE_FAST        = 162,

    LED_WIPE_SLOW          = 170,
    LED_WIPE               = 171,
    LED_WIPE_FAST          = 172,

    LED_GRADIENT           = 180,
    LED_GRADIENT_CENTER    = 181,

    LED_SPARKLE_THIN       = 190,
    LED_SPARKLE            = 191,
    LED_SPARKLE_DENSE      = 192,

    LED_LIGHTNING_RARE     = 200, 
    LED_LIGHTNING          = 201,
    LED_LIGHTNING_WILD     = 202,

    LED_CHASE_SLOW         = 210,
    LED_CHASE              = 211,
    LED_CHASE_FAST         = 212
};

class LedController
{
    public:
        LedController() = default;
        void begin();

        void set_input(CRGB color);
        void set_input(TubeInput input);
        void set_input(PixelControlInput input);

        void handle();

    private:
        uint8_t effect = LED_SOLID;
        CRGB color = CRGB::Black;
        CRGB leds[NUM_LEDS] = {};

        uint8_t heat[NUM_LEDS] = {};

        unsigned long last_frame_ms = 0;
        unsigned long effect_start_ms = 0;

        void set_effect(uint8_t new_effect);
        void hsv2rgb_rainbow(uint8_t hue, uint8_t sat, uint8_t val, uint8_t &red, uint8_t &green, uint8_t &blue);
        uint8_t exponential_increase(uint8_t x);
        void fill_solid(struct CRGB * target_array, int num_to_fill, const struct CRGB& color);

        /* Drawing primitives shared by the effects. */
        void clear();        
        CRGB scaled_color(uint8_t brightness);
        void draw_block(int16_t position);
        int16_t sweep_position(uint32_t phase, uint16_t period_ms);
        void draw_tail(int16_t head, uint8_t length, int8_t direction);
        CRGBPalette16 fire_palette();

    
        void solid_color_mode();
        void pulse(uint32_t elapsed, uint16_t period_ms);
        void bottom_to_top(uint32_t elapsed);
        void top_to_bottom(uint32_t elapsed);
        void up_and_down(uint32_t elapsed);
        void strobo(uint32_t elapsed);
        void rainbow_solid(uint32_t elapsed);
        void rainbow_flow(uint32_t elapsed, uint16_t period_ms);
        void comet(uint32_t elapsed, uint16_t period_ms);
        void scanner(uint32_t elapsed, uint16_t period_ms);
        void center_out(uint32_t elapsed, uint16_t period_ms);
        void fire(uint8_t cooling, uint8_t sparking);
        void plasma(uint32_t elapsed, uint8_t speed);
        void bounce(uint32_t elapsed, uint16_t period_ms);
        void wipe(uint32_t elapsed, uint16_t period_ms);
        void gradient(bool from_center);
        void sparkle(uint8_t chance);
        void lightning(uint32_t elapsed, uint16_t gap_ms);
        void chase(uint32_t elapsed, uint16_t period_ms);
};

#endif
